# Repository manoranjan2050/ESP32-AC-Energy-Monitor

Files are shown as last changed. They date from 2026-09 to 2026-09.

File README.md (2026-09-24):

# ESP32-S3 AC Energy Monitor (6 CT + voltage), ESPHome / Home Assistant

An open-source, DIY mains energy monitor built on an **ESP32-S3 DevKit**:
- up to **6 SCT-013 current transformers (CTs)**, each channel works with **100A/50mA** or **30A/1V** CTs
- one **ZMPT101B** voltage sensor
- **ESPHome** firmware, visible in **Home Assistant**

> **⚠ Not a certified energy meter.** The ESP32 ADC is noisy and non-linear. Don't use this for
> billing or protection. The board has a **230 V section**, so build and test it only if you're
> competent with mains wiring.

---

## Project status (2026-09-24)

| Part | Status |
|---|---|
| Stage-1 test firmware (1 CT, true RMS, calibration in HA) | ✅ Working (`esphome/energy_monitor_test.yaml`) |
| CT input circuit (bias + 1k/1.8k + 104 + burden) | ✅ **Proven on a breadboard** with both CT types (results below) |
| Custom PCB v0.1 (KiCad): 6 CT + on-board ZMPT101B | ✅ Designed and **fully routed**. ERC 0, DRC 0 errors, schematic ↔ PCB parity 0. **Not built yet** |
| On-board ZMPT101B + MCP6002 voltage stage | ⚠ Designed, **not tested yet** |
| 6-channel + voltage firmware (real power, PF, kWh) | ⏳ Next step (after the PCB) |

### Breadboard test results (CT channel = same values as the PCB)

| CT | Load | Reading | Notes |
|---|---|---|---|
| 30A/1V | CT unclamped | ~0.08 A | Noise floor |
| 30A/1V | Light + fan | **0.33 A** | ≈ 75 W |
| 30A/1V | Water heater | **12.66 A** | Clean sine (pp/rms 2.86), no clipping |
| 100A/50mA + 24 Ω burden | Induction cooker | **4.6 A** | Stable, no clipping |

---

## Repository map

```
esphome/
  energy_monitor_test.yaml      Stage-1 test firmware (1 CT on GPIO1)
  secrets.example.yaml          Copy to secrets.yaml (git-ignored) and fill in Wi-Fi/keys
docs/wiring.md                  Stage-1 breadboard wiring checks
hardware/
  README.md                     PCB design notes, calculations, before-ordering checklist
  kicad/                        KiCad 10 project (schematic + routed PCB + ZMPT101B footprint + DRC rules)
  fab/                          Manufacturing files: Gerbers zip, BOM, pick-and-place, KiCad zip
  renders/                      Diagrams (SVG), PCB images, schematic PDF
  generate_kicad.py             Builds schematic + PCB from ONE netlist (source of truth)
  route_pcb.py                  Hand-routes mains, autoroutes the rest with Freerouting
  make_*_svg.py                 Regenerate the SVG diagrams from the same netlist
```

---

## Files you'll use

### KiCad (schematic + PCB)

| File | What it is |
|---|---|
| [`hardware/kicad/ct6-energy-monitor.kicad_pro`](hardware/kicad/ct6-energy-monitor.kicad_pro) | **Open this in KiCad 10** (free, kicad.org). The schematic and PCB open together |
| [`hardware/kicad/ct6-energy-monitor.kicad_sch`](hardware/kicad/ct6-energy-monitor.kicad_sch) | Schematic: 81 parts, 42 nets |
| [`hardware/kicad/ct6-energy-monitor.kicad_pcb`](hardware/kicad/ct6-energy-monitor.kicad_pcb) | Routed 2-layer PCB, 120 × 90 mm |
| [`hardware/fab/ct6-kicad-project.zip`](hardware/fab/ct6-kicad-project.zip) | The whole KiCad project in one zip |
| [`hardware/renders/schematic.pdf`](hardware/renders/schematic.pdf) | Schematic as a PDF, for viewing and printing |

### EasyEDA

- **EasyEDA Pro:** *File → Import → KiCad*, then pick `ct6-energy-monitor.kicad_pro` or `ct6-kicad-project.zip`.
  The files are **KiCad 10 format**, and EasyEDA's importer may only accept older KiCad versions (**not tested**).
- **EasyEDA Standard:** only imports old KiCad 5 files, so it won't work.
- **If the import fails**, you have three options:
  1. **Order straight from the Gerbers** (below). The board is already routed, so no EasyEDA is needed.
  2. **Redraw in EasyEDA** using [`easyeda_connection_guide.svg`](hardware/renders/easyeda_connection_guide.svg).
     It shows every part, every pin and its net name. Place the parts, put a **Net Label** with the exact
     name on each pin, then check the nets against the list in section 7 of that SVG.
  3. Ask for a **KiCad 6-format copy** of the schematic, which EasyEDA Pro is more likely to accept.

### Ordering (JLCPCB)

| File | Use |
|---|---|
| [`hardware/fab/ct6-gerbers-jlcpcb.zip`](hardware/fab/ct6-gerbers-jlcpcb.zip) | Upload as-is: Gerbers + drill, 2 layers |
| [`hardware/fab/ct6-bom.csv`](hardware/fab/ct6-bom.csv) | Bill of materials |
| [`hardware/fab/ct6-cpl.csv`](hardware/fab/ct6-cpl.csv) | Pick-and-place, origin = bottom-left board corner |

### Diagrams (SVG, open in any browser)

| Diagram | Shows |
|---|---|
| [`pcb_full_connection.svg`](hardware/renders/pcb_full_connection.svg) | **The complete PCB circuit**: every R, C, diode, jumper, op-amp pin and GPIO |
| [`easyeda_connection_guide.svg`](hardware/renders/easyeda_connection_guide.svg) | Every part as a card: pin → net name. Use it for EasyEDA redraws and checks |
| [`final_6ct_voltage_connection.svg`](hardware/renders/final_6ct_voltage_connection.svg) | Breadboard version: 6 CT + ready-made ZMPT101B module |
| [`breadboard_connection.svg`](hardware/renders/breadboard_connection.svg) | Breadboard test of one CT channel (the proven circuit) |
| [`pcb_top.png`](hardware/renders/pcb_top.png), [`pcb_copper.png`](hardware/renders/pcb_copper.png) | PCB 3D render and copper view |

---

## How the circuit works

### GPIO map (ESP32-S3, ADC1 only)

| Signal | GPIO | DevKit socket pin |
|---|---|---|
| CT1 | GPIO1 | J4-4 |
| CT2 · CT3 · CT4 · CT5 | GPIO4 · 5 · 6 · 7 | J3-4 · 5 · 6 · 7 |
| CT6 | GPIO8 | J3-12 |
| Voltage (ZMPT101B) | GPIO9 | J3-15 |
| Bias monitor | GPIO10 | J3-16 |
| I²C OLED SDA / SCL | GPIO17 / GPIO18 | J3-10 / J3-11 |
| 5V in / 3V3 / GND | — | J3-21 / J3-1,2 / J3-22, J4-1,21,22 |

Avoid GPIO0/3/45/46 (strapping), GPIO35–37 (octal PSRAM on N16R8) and GPIO11–20 (ADC2, conflicts with Wi-Fi).
**Measure your DevKit before ordering.** On the test board the silkscreen "4" was really GPIO1.

### One CT channel (×6, identical)

```
CT sleeve ─────────────────────────────────────── VB (bias ≈ 1.5 V)
CT tip ──┬── 1 kΩ ──┬── ADC node ──► GPIO
         │          ├── 1.8 kΩ ──► VB
       22 Ω         ├── 100 nF (104) ──► GND
     (burden,       └── BAT54S clamp (to GND and +3V3A)
   via jumper JP)
```

- **1 kΩ + 1.8 kΩ** scale the signal to **×0.643** around the bias. This gives headroom for 100 A, and the 1 kΩ limits current into the pin.
- **100 nF** filters noise (~2.5 kHz).
- **BAT54S** clamps the pin between 0 and 3.3 V. See "Diodes" below.

### Jumpers JP11…JP16 (one per CT)

| CT type | Shunt position | Burden | Home Assistant settings |
|---|---|---|---|
| **100A/50mA** (SCT-013-000) | **1-2 (mA), default** | IN | Burden **22** (or 24) · Secondary **0.05** · Primary **100** · Calibration **1.555** |
| **30A/1V** (SCT-013-030) | **2-3 (V)** | OUT | Burden **1** · Secondary **1** · Primary **30** · Calibration **1.555** |

- **1.555** undoes the ×0.643 divider. Fine-tune each channel: `Cal = 1.555 × (clamp-meter A ÷ reading A)`.
- **A 1V CT with the shunt on mA** reads ~25 % of the true value. That's safe, just obviously wrong.
- **⚠ A 100A CT with the shunt on V runs OPEN.** The reading clips to 0/4095 and can damage the CT or the pin. **Unclamp immediately.**
- Ship boards with every shunt on **1-2**.

### Diodes (D…)

| Designator | Part | Job |
|---|---|---|
| **D1** | SS34 Schottky | Power input: reverse-polarity protection, and stops USB 5V back-feeding your 5V supply |
| **D11 … D16** | BAT54S | ADC clamps for **CT1 … CT6** (D1**n** = CT**n**, so **D16 = CT6 → GPIO8**) |
| **D41** | BAT54S | ADC clamp for the voltage channel (GPIO9) |

A **BAT54S** is two Schottky diodes in series in one SOT-23:
- **pin 1 = GND side**
- **pin 2 = +3V3A side**
- **pin 3 = ADC node**

It does nothing while the signal is between 0 and 3.3 V. If a fault pushes the pin outside that range (for example a CT without its burden), it clamps the pin. The 1 kΩ in front limits the current. The clamps were optional on the breadboard; **fit them on the PCB.**

### Parts naming (per CT channel n = 1…6)

`J1n` jack · `R1n1` 22 Ω burden · `JP1n` mA/V jumper · `R1n2` 1 kΩ · `R1n3` 1.8 kΩ · `C1n` 100 nF · `D1n` BAT54S

### Resistor colour codes (4-band)

| Value | Bands |
|---|---|
| 10 kΩ | brown · black · orange |
| 1 kΩ | brown · black · red |
| 1.8 kΩ | brown · grey · red |
| 22 Ω | red · red · black |
| 24 Ω | red · yellow · black |
| 18 Ω | brown · grey · black (⚠ not 18 kΩ = brown · grey · orange) |

A ceramic cap marked **104** = 100 nF; **103** = 10 nF; **473** = 47 nF.

---

## Working on another PC

```bash
git clone https://github.com/manoranjan2050/ESP32-AC-Energy-Monitor.git
```

- **PCB:** install KiCad 10 and open `hardware/kicad/ct6-energy-monitor.kicad_pro`.
- **Firmware:** copy `esphome/secrets.example.yaml` to `esphome/secrets.yaml` (git-ignored) and fill in your Wi-Fi and keys.
- **Regenerate** (optional; this overwrites the KiCad files, so **don't** run it after editing the board by hand):

  ```bash
  "C:/Program Files/KiCad/10.0/bin/python.exe" hardware/generate_kicad.py
  ```

## Before ordering the PCB

1. Measure the **DevKit header row spacing** (22.86 mm) and check every pin used.
2. Check the **ZMPT101B pin grid**: 10.0 × 12.7 mm, with calipers.
3. **Screw terminals:** the wire entry faces the board edge.
4. Keep the **6.5 mm mains creepage** and the **slot under T1**.
5. **First power-up without mains and without CTs.** Expect +3V3A ≈ 3.3 V, VB ≈ 1.50 V, and every CTn_ADC / V_ADC ≈ 1.50 V.

Full details are in [`hardware/README.md`](hardware/README.md).

---

## Next steps

1. Order and build PCB v0.1, then test it: the CT channels first, then the on-board voltage stage (untested so far).
2. **6-channel + voltage ESPHome firmware:**
   - per-channel CT type, ratio and calibration
   - V + I sampled together for **real power, power factor, frequency and kWh**
   - Home Assistant **Energy dashboard** support

---

# Stage-1 test firmware guide (1 CT, breadboard)

> The sections below document the **first single-CT test**. Its bias circuit (10k/10k) and direct CT
> wiring were the starting point. The **final, proven channel circuit** adds the 1 kΩ / 1.8 kΩ / 104
> network shown above: use [`breadboard_connection.svg`](hardware/renders/breadboard_connection.svg) and set
> **Calibration 1.555**.

- Board: **ESP32-S3** (QFN56 rev v0.2, 16 MB flash, 8 MB PSRAM, native USB)
- ESPHome: **2026.8.2**, esp-idf framework
- Firmware: [`esphome/energy_monitor_test.yaml`](esphome/energy_monitor_test.yaml)
- Wiring checks: [`docs/wiring.md`](docs/wiring.md)

## 1. Hardware wiring (overview)

```
                     ESP32-S3 3V3
                          │
                         10k
                          │
             ┌────────────┼──────────── BIAS node (~1.65 V)
             │            │                 │
             │           10k            [10 µF, optional
             │            │              but recommended]
             │           GND                │
             │                             GND
   SCT-013-000
   ┌───────────┐
   │ lead A ───┼──────────┬──────── BIAS node
   │           │         22 Ω   (burden, directly across the CT leads)
   │ lead B ───┼──────────┴──────── ESP32-S3 GPIO1 (ADC1_CH0)
   └───────────┘
```

The CT drives an AC voltage across the 22 Ω burden. Because one end of the
burden sits on the 1.65 V bias node, the ADC pin sees **1.65 V ± the AC signal**.

## 2. ESP32 ADC pin configuration

Set the pin in the `substitutions:` block. Give the GPIO **number only**:

```yaml
ct_gpio: "1"     # GPIO1 = ADC1 channel 0 (check the pin electrically; header labels can be misleading)
```

On the ESP32-S3 use an **ADC1 pin, GPIO1 to GPIO10**. Skip GPIO3 (it's a strapping pin).
Don't use ADC2 (GPIO11 to GPIO20), because Wi-Fi uses ADC2.

- Attenuation is **12 dB**. On the S3 that gives about 0 to 3.1 V of usable range.
- Every sample is converted with ESP-IDF's **eFuse curve-fitting calibration**,
  so the ADC is not treated as linear. The diagnostic entity
  **CT ADC Calibration** shows which scheme is active. If it says
  `UNCALIBRATED`, the linear 3.3 V/4095 fallback is in use and the voltages are rough.

## 3. The 22 Ω burden resistor

The SCT-013-000 is a **current-output CT** (100 A : 50 mA) and has **no internal burden**.
The 22 Ω resistor turns its current into a voltage:

| Primary current | Secondary current | Burden RMS | Burden peak | ADC swing (around 1.65 V) |
|---|---|---|---|---|
| 1 A | 0.5 mA  | 11 mV | 15.6 mV | ±0.016 V |
| 4.35 A (1 kW) | 2.17 mA | 47.9 mV | 67.7 mV | ±0.068 V |
| 10 A | 5 mA | 110 mV  | 156 mV  | ±0.156 V |
| 50 A | 25 mA | 550 mV  | 778 mV  | ±0.78 V |
| ~90 A | 45 mA | 990 mV  | 1.40 V  | about the S3 ADC limit |
| 100 A | 50 mA | 1.10 V  | 1.556 V | **clips** (0.09 to 3.21 V) |

With 22 Ω the usable range is about 0 to 90 A. The **CT Clipped Samples** entity counts samples at the ADC rails.

## 4. The 2 × 10 k bias circuit

The two 10 k resistors from 3V3 to GND make a mid-rail point (~1.65 V), so the AC
signal swings around it instead of going below 0 V. Put a
**10 µF to 100 µF capacitor from the bias node to GND**. Without it the bias node
picks up ripple and noise, which shows up as a higher no-load RMS. The firmware
measures the real bias every window (**CT Bias Voltage**), so it doesn't need to be exactly 1.65 V.

## 5. SCT-013-000 connection

The 3.5 mm jack uses **tip** and **sleeve** for the two secondary leads. The ring is
normally unused. Polarity doesn't matter for RMS. Use a 3.5 mm breakout, or cut
the plug and solder the leads. **Fit the burden before clamping the CT on anything.**

## 6. Flashing the ESP32-S3

**Option A: ESPHome Builder (Home Assistant add-on)**
1. ESPHome Builder → **Secrets** (top-right). Add the lines from
   `esphome/secrets.yaml` (not in git; copy `esphome/secrets.example.yaml` and fill in your values) (`wifi_ssid`, `wifi_password`, `ct_test_api_key`,
   `ct_test_ota_password`, `ct_test_ap_password`).
2. **+ New device** → *Continue* → *Skip* the wizard, or create any device and then
   **Edit** it. Replace the whole YAML with `energy_monitor_test.yaml` and save.
3. **Install** → *Plug into this computer* (Chrome/Edge Web Serial), or
   *Manual download* → *Factory format* and flash with web.esphome.io.
4. Later updates can go over the air: **Install → Wirelessly**.

**Option B: ESPHome CLI on this PC**
```bash
cd "D:/My Project/ElectroIoT/ESP32-AC-Energy-Monitor/esphome"
```
```bash
python -m esphome run energy_monitor_test.yaml --device COM5
```
If the S3 won't enter download mode, hold **BOOT**, tap **RST**, then release BOOT.

## 7. Adding it to Home Assistant

The device uses the ESPHome native API, so HA should discover it automatically
(**Settings → Devices & services → Discovered: CT Energy Test → Configure**). When
asked for the encryption key, enter the `ct_test_api_key` value. If it isn't
discovered, add the **ESPHome** integration manually with host `ct-energy-test.local`
(or its IP address) and port `6053`.

Entities (all published together every **5 s**, one window each):

| Entity | Meaning |
|---|---|
| CT Raw ADC | Last raw 12-bit sample in the window |
| CT ADC Voltage | Last sample converted to volts (calibrated) |
| CT Bias Voltage | Mean of the window, which is the DC bias the RMS is taken around |
| CT Minimum / CT Maximum | Lowest and highest raw counts in the window |
| CT Peak-to-Peak | Calibrated V(max) − V(min) |
| CT AC RMS | **True RMS of the AC part across the burden** (bias removed; 400 samples over 10 cycles) |
| CT Secondary / Primary Current (estimated) | Only while **CT Current Estimate Enabled** is on |
| CT Burden Resistance, CT Rated Primary/Secondary Current, CT Calibration Factor | Editable config numbers, kept across reboots |
| CT Clipped Samples, CT Actual Sample Rate, CT ADC Calibration | Diagnostics |

The current estimate is:
```
secondary_A = CT_AC_RMS / burden_resistance
primary_A   = secondary_A × (ct_primary_current / ct_secondary_current) × calibration_factor
```

## 8. Expected values with NO load (CT unclamped or on a dead cable)

| Entity | Expected |
|---|---|
| CT Bias Voltage | ~1.60 to 1.70 V (depends on the 3V3 rail and resistor tolerance) |
| CT Raw ADC / Min / Max | Around the bias count, roughly 1900 to 2300, with Min and Max only a few dozen counts apart |
| CT Peak-to-Peak | Small, about 10 to 60 mV (ADC noise) |
| CT AC RMS | **Low, about 1 to 10 mV** (noise floor) |
| CT Clipped Samples | 0 |
| CT Actual Sample Rate | ~2000 Hz |

Note your no-load RMS. It is the noise floor. As a rough guide, 5 mV of noise
equals about 0.45 A of "phantom" primary current.

## 9. What changes when you clamp a live conductor

Clamp **one** insulated conductor (live **or** neutral), not the whole cable. If
you clamp live and neutral together, their currents cancel and you read about 0.

With a **1000 W resistive load** (~4.35 A at 230 V):

| Entity | Load off | Load on (theory) |
|---|---|---|
| CT Bias Voltage | ~1.65 V | **Unchanged** (~1.65 V) |
| CT Min / Max | ±a few counts | Spread out by roughly ±85 counts |
| CT Peak-to-Peak | ~0.03 V | **~0.14 V** |
| CT AC RMS | ~0.005 V | **~0.048 V** |
| Primary Current (est., if enabled) | ~0.2 to 0.5 A (noise) | **~4.3 A** |

The HA history graph for **CT AC RMS** should step up when the load turns on and
drop when it turns off. To calibrate, compare against a trusted clamp meter and set
`CT Calibration Factor = meter_amps / estimated_amps`. Tip: pass the conductor
through the CT **5 times** (5 turns), so 4.35 A reads like 21.7 A. That gives a much
better signal-to-noise ratio for calibration (divide by 5 afterwards).

## 10. Safety warnings

- **Mains voltage (230 V AC) can kill.** Only clamp an insulated conductor.
  Never open or modify live wiring on a breadboard setup. If you're unsure, have a
  licensed electrician install the CT.
- **Never leave the SCT-013-000 secondary open-circuit while it's clamped on a
  loaded conductor.** A current-output CT with no burden can produce dangerously
  high voltages and damage itself. Keep the 22 Ω burden fitted whenever the CT is
  plugged in or clamped.
- **Never connect the CT directly to the ESP32 without the burden and bias.** The
  ADC pin must stay between 0 V and 3.3 V. A loose bias wire leaves the pin
  swinging below 0 V, which can damage the GPIO.
- The burden must match the current range. 22 Ω clips above ~90 A. For higher
  currents use a smaller burden (for example 18 Ω).
- The ESP32 is powered from USB and is **not isolated from anything except through
  the CT's own insulation**. Keep the breadboard away from the mains side.
- This firmware is not a certified meter. Don't use it for billing, protection, or
  safety decisions.

---

## Original roadmap (written before the 1-channel test)

The 1-channel test has since passed, and the 6-CT PCB is designed. See **Project status** and **Next steps** at the top of this README.

```
ESP32-S3
├── CT1 … CT8   (ADC1 GPIO1..10; per-channel burden + calibration)
└── ZMPT101B    (voltage)
```
Planned: RMS voltage, RMS current per CT, real/apparent power, power factor,
frequency, kWh with the HA Energy dashboard, per-channel calibration, MQTT option, and OTA.
Eight CTs plus a ZMPT101B is 9 analog inputs, which fits in ADC1's 10 pins on the S3. Real power needs
V and I sampled nearly at the same time, so the stage-2 design will use interleaved sampling (or an external
ADC such as the ADS1115/ADS131M08).

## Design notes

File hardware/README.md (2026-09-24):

# CT6 Energy Monitor PCB (v0.1): ESP32-S3 DevKit + 6 CT + ZMPT101B

KiCad 10 project: [`kicad/ct6-energy-monitor.kicad_pro`](kicad/ct6-energy-monitor.kicad_pro)
**Full circuit diagram (every R/C/jumper/GPIO): [`renders/pcb_full_connection.svg`](renders/pcb_full_connection.svg)** · Schematic PDF: [`renders/schematic.pdf`](renders/schematic.pdf) · 3D top view: [`renders/pcb_top.png`](renders/pcb_top.png) · BOM: [`bom.csv`](bom.csv)

> **Status: v0.1 fully routed. Not yet built or tested; do the breadboard test and the checklist below first.**
> ERC: 0 violations · DRC: 0 errors, **0 unconnected**, 0 creepage/clearance · schematic-to-PCB parity: 0 issues.
> Remaining DRC warnings are cosmetic only (silkscreen text overlaps, and the jack's edge marker moved off Edge.Cuts).

**Manufacturing files** (`fab/`):
- `ct6-gerbers-jlcpcb.zip`: Gerbers + drill, upload to JLCPCB as-is
- `ct6-bom.csv` and `ct6-cpl.csv`: BOM and pick-and-place (origin = bottom-left board corner)
- `ct6-kicad-project.zip`: the whole KiCad project

**EasyEDA:** EasyEDA Pro → *File → Import → KiCad*, then select `ct6-kicad-project.zip` (or the `.kicad_pro`).
The files are KiCad 10 format; if your EasyEDA version refuses them, order from the Gerber zip instead.
EasyEDA Standard only imports old KiCad 5 files.

Everything is generated from one netlist in [`generate_kicad.py`](generate_kicad.py), and routed by [`route_pcb.py`](route_pcb.py):
1. The 230 V nets are hand-routed as locked 0.8 mm tracks.
2. **Freerouting 1.9.0** autoroutes the rest, with the whole mains block (+6.5 mm) set as a keepout.
3. The GND pour is added last.

```bash
set CT6_NO_ZONES=1
"C:/Program Files/KiCad/10.0/bin/python.exe" hardware/generate_kicad.py
"C:/Program Files/KiCad/10.0/bin/python.exe" hardware/route_pcb.py path/to/freerouting-1.9.0.jar
```

⚠ Both scripts overwrite the `.kicad_pcb`. **If you edit the board by hand in KiCad, stop rerunning them.**

---

## Block diagram

```
 5V terminal / USB-C ─ polyfuse ─ SS34 ─► DevKit 5V ──► DevKit 3V3 ─ ferrite ─► +3V3A (analog)
                                                                               │
 +3V3A ─ 12k/10k ─► MCP6002-A buffer ─ 47R ─► VB = 1.50 V (10µF+100nF) ────────┼──► GPIO10 (bias monitor)
                                                                               │
 CT1..CT6 jack ─► [22R burden via mA/V jumper] ─ 1k ─┬─ 1k8 → VB              │
                                                      ├─ 100nF → GND           │
                                                      └─ BAT54S clamp ─► GPIO1,4,5,6,7,8
                                                                               │
 230V L/N ─ fuse 100mA ─ MOV ─ 4×220k ─► ZMPT101B ─► MCP6002-B TIA (2k7‖47nF) ─ 1k ─ BAT54S ─► GPIO9
```

## CT input channel (copied from KinCony KC868-M16v2, per channel)

| Part | Value | Purpose |
|---|---|---|
| J1n | 3.5 mm jack (SJ1-3523N) | **Tip = signal, Sleeve = VB**, Ring unused (SCT-013 wiring) |
| R1n1 | **22 Ω 0.1 %** | Burden for **mA-type** CTs (SCT-013-000 100 A/50 mA) |
| JP1n | 3-pin header | **1-2 = mA** (burden in, **ship with this fitted**); **2-3 = V** (burden out, for 1 V CTs such as SCT-013-030) |
| R1n2 / R1n3 | 1 kΩ / 1.8 kΩ 1 % | Attenuator: ×0.643 around VB. The 1 k limits current into the pin; the 1k8 holds an empty jack at VB |
| C1n | 100 nF | Anti-alias / noise filter, ~2.5 kHz |
| D1n | BAT54S | Clamps the ADC pin between GND and 3V3A |

**Headroom at the ADC pin** (1.50 V bias; S3 12 dB range is about 0 to 3.1 V):

| CT | At full scale | At the pin |
|---|---|---|
| SCT-013-000 + 22 Ω (jumper **mA**) | 100 A → 1.10 V RMS | ±1.00 V peak → 0.50 to 2.50 V ✅ |
| SCT-013-030 1 V (jumper **V**) | 30 A → 1.00 V RMS | ±0.91 V peak → 0.59 to 2.41 V ✅ |

Firmware scale (amps per RMS volt **measured at the pin**) = CT ratio ÷ 0.643:
- 100 A/50 mA + 22 Ω: 100 / 0.05 / 22 / 0.643 = **141.4 A/V**
- 30 A/1 V: 30 / 0.643 = **46.7 A/V**

Then fine-tune each channel's calibration factor against a clamp meter.

A **wrong jumper in one direction is safe**: a 1 V CT with the jumper on mA reads only **~25 % of the true value**, because its internal ~67 Ω burden ends up in parallel with the 22 Ω. It's obviously wrong, but harmless. **The dangerous case is an mA CT with the jumper on V.** In that state the CT runs open (the 0/4095 clipping from the breadboard test). That is why mA is the default and the 1k series resistor plus BAT54S protect the pin.

## Voltage channel (ZMPT101B, on board)

- **Primary:** 230 V → F2 100 mA T → 4 × 220 kΩ 1206 (880 kΩ, 57 V per resistor) → 0.26 mA. RV1 (275 VAC MOV) across L/N after the fuse.
- **Secondary:** into MCP6002-B used as a **transimpedance amplifier** with its + input at VB. Output = VB − 0.26 mA × 2.7 kΩ = **1.50 V ± 0.70 V RMS** (±1.0 V peak at 230 V, ±1.2 V at 270 V). 47 nF in parallel sets a ~1.25 kHz roll-off.
- Output goes through 1 kΩ + 100 nF + BAT54S to GPIO9. Calibrate volts in firmware; there's no trimmer.

## GPIO map (ESP32-S3, all ADC1)

| Signal | GPIO | DevKitC-1 pin |
|---|---|---|
| CT1 | GPIO1 | J3-4 (right header) |
| CT2 to CT6 | GPIO4, 5, 6, 7, 8 | J1-4..7, J1-12 (left header) |
| Voltage | GPIO9 | J1-15 |
| Bias monitor | GPIO10 | J1-16 |
| I2C OLED SDA / SCL | GPIO17 / GPIO18 | J1-10 / J1-11 |

Not used: GPIO0/3/45/46 (strapping), GPIO35 to 37 (octal PSRAM on N16R8), GPIO11 to 20 (ADC2, conflicts with Wi-Fi).

## PCB (120 × 90 mm, 2-layer)

- **Mains block** (top-left) is fenced by an **L-shaped 1.6 mm routed slot**. The slot's vertical leg runs **under the ZMPT101B** between primary and secondary pins (10 mm pin-to-pin).
- **Custom DRC rules** (`kicad/ct6-energy-monitor.kicad_dru`): **6.5 mm clearance and creepage** from any `AC_*` net to all low-voltage copper.
- **GND pour** on both layers covers the LV area only. It excludes the mains block and the **DevKit antenna area** (top-right; the DevKit's antenna end sits at the top board edge).
- CT jacks sit on the bottom edge. The DevKit's USB end points down into a clear area, so you can still plug in a USB cable for flashing.

## Before ordering (checklist)

1. **Measure your DevKit.** Header row spacing is set to **22.86 mm** (`DEVKIT_ROW_SPACING`), and the pin order is ESP32-S3-DevKitC-1. Your breadboard test showed the silkscreen didn't match the actual pin (the wire on "4" was GPIO1). **Check every pin used here with a meter or the pin-scan firmware.**
2. **ZMPT101B footprint:** 10.0 × 12.7 mm pin grid, cross-checked against two independent KiCad libraries. Check it against your part with calipers.
3. **Screw terminals J1/J5:** make sure the wire entry faces the board edge (rotate 180° in KiCad if not).
4. **Review the autorouted tracks** in KiCad. Autorouters are functional, not beautiful. The CT signal traces to the DevKit are long diagonals, which is fine at 50 Hz, but you may want to tidy them.
5. After any change, run DRC. It must show **0 unconnected items and 0 creepage errors**.
6. Mains safety: 230 V on a PCB needs an enclosure, a fuse, and no exposed metal. The ZMPT101B is the isolation barrier, so don't bypass it.

## Firmware

Not written yet. Extending `esphome/energy_monitor_test.yaml` to 6 CT + V gives:
- per-channel `ct_gpio`, CT type (mA/V), ratio and calibration
- interleaved V + I sampling for real power, PF and kWh

The on-board **attenuator (×0.643) must be included** in the scale; see the formulas above.

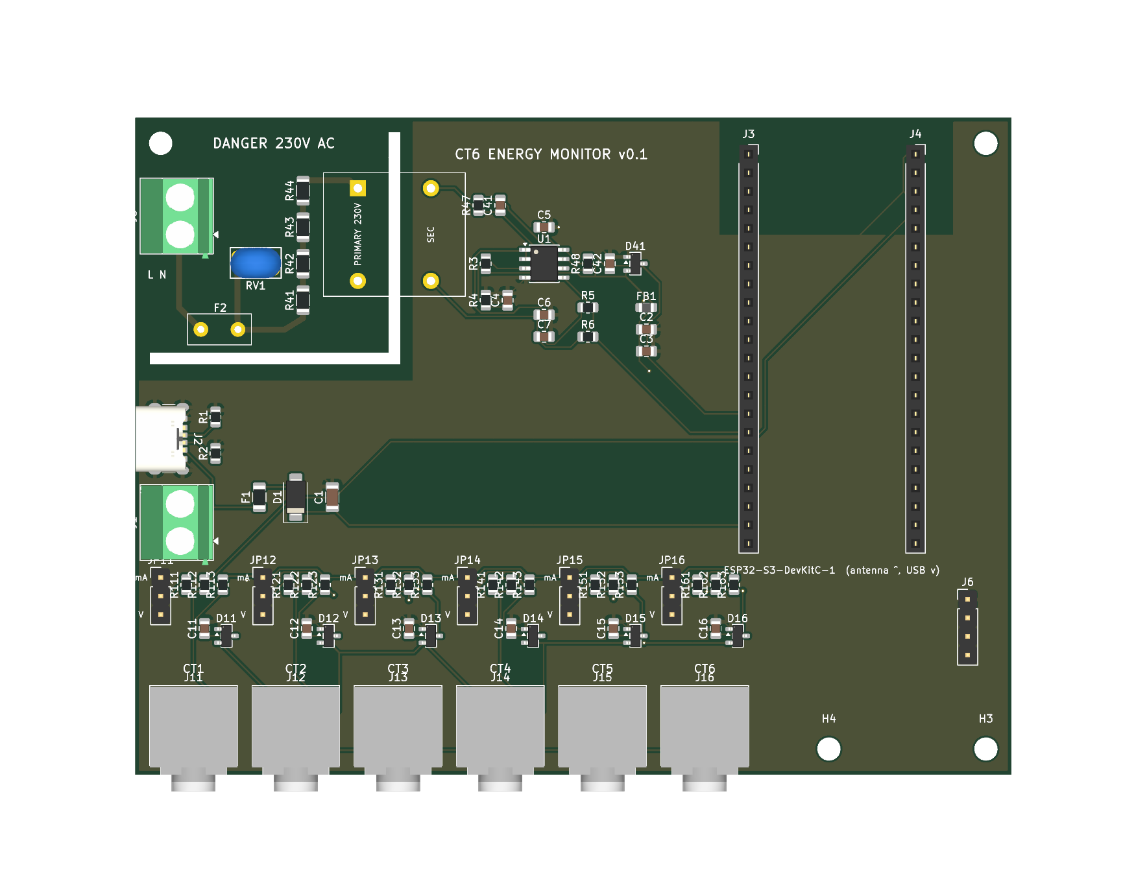
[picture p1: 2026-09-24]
hardware/renders/pcb_top.png

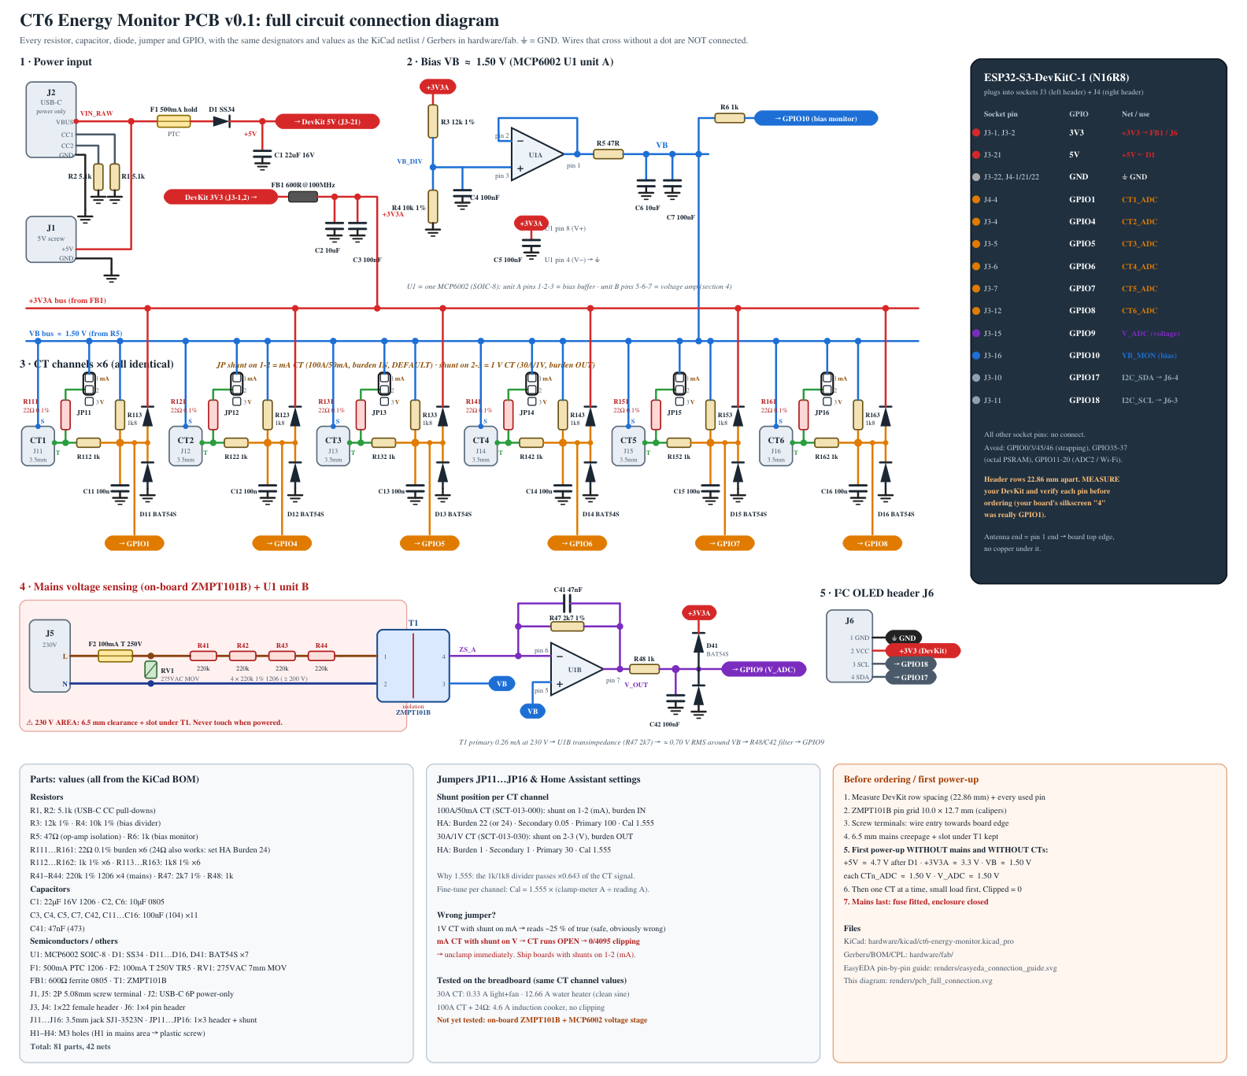
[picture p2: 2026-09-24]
hardware/renders/pcb_full_connection_preview.png

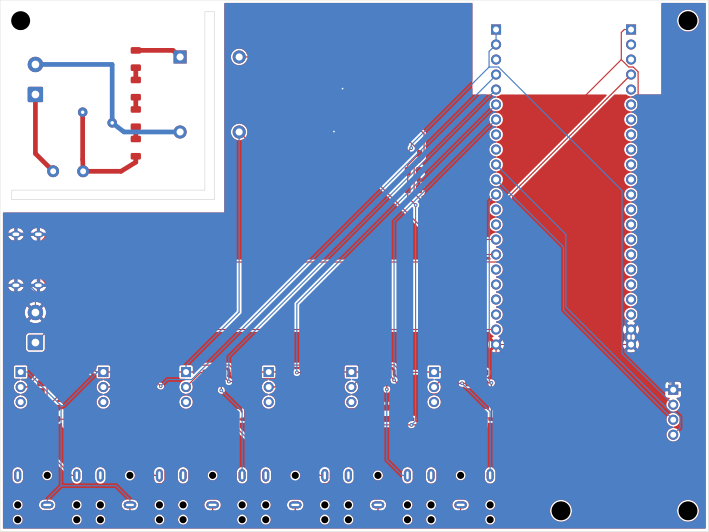
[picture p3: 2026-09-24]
hardware/renders/pcb_copper.png

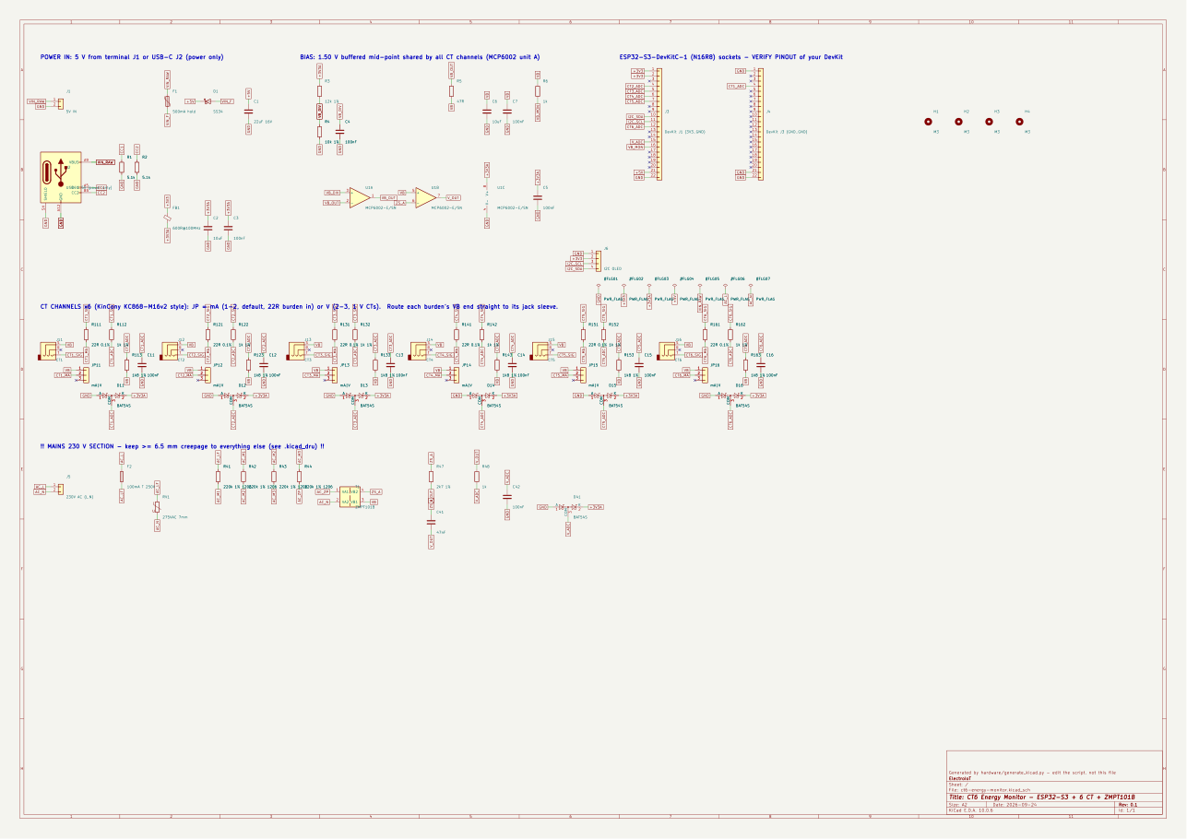
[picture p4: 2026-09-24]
hardware/renders/schematic.png

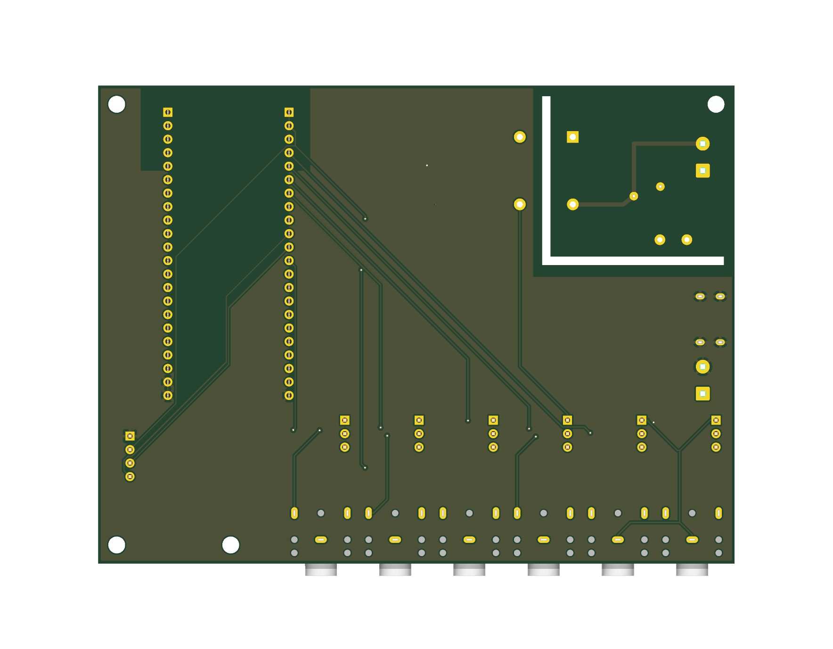
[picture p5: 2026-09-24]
hardware/renders/pcb_bottom.png

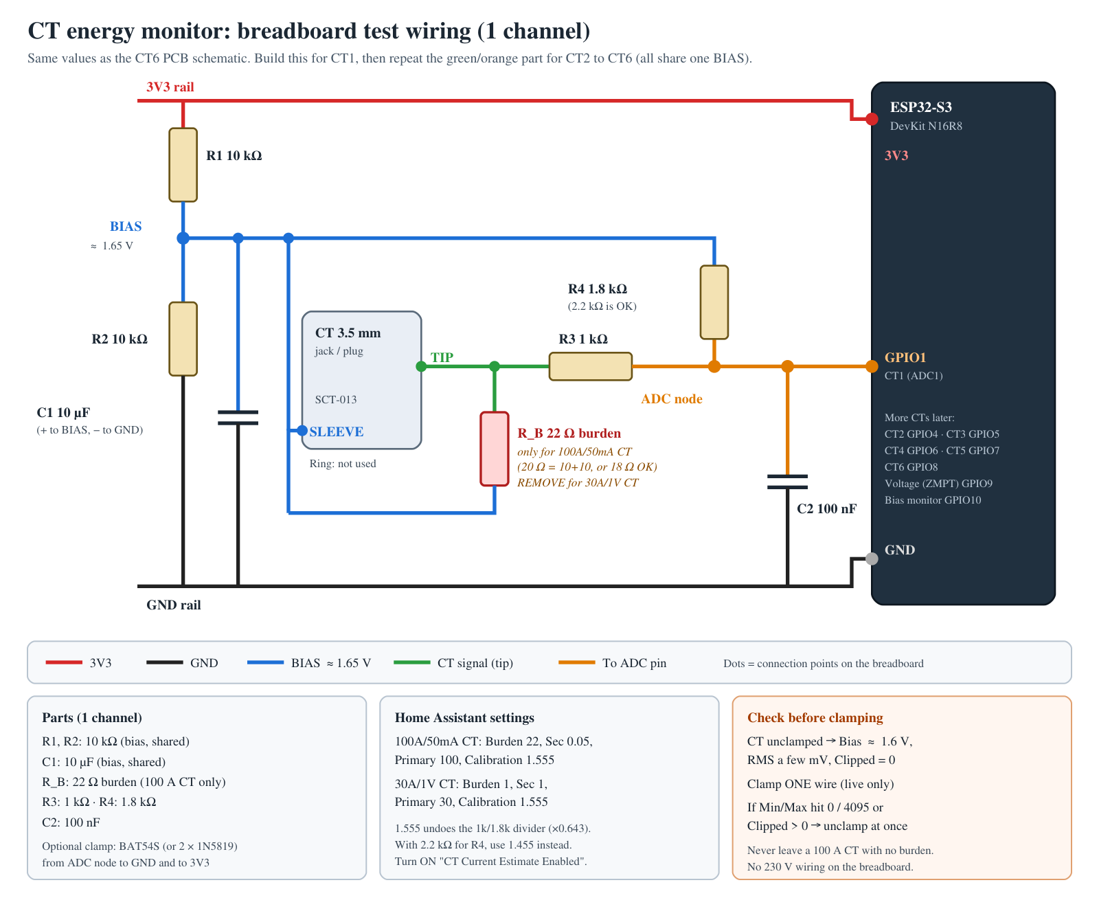
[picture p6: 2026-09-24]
hardware/renders/breadboard_preview.png

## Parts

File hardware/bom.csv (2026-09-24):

Reference | Value | Footprint | QUANTITY
C1 | 22uF 16V | Capacitor_SMD:C_1206_3216Metric | 1
C2,C6 | 10uF | Capacitor_SMD:C_0805_2012Metric | 2
C3-C5,C7,C11-C16,C42 | 100nF | Capacitor_SMD:C_0805_2012Metric | 11
C41 | 47nF | Capacitor_SMD:C_0805_2012Metric | 1
D1 | SS34 | Diode_SMD:D_SMA | 1
D11-D16,D41 | BAT54S | Package_TO_SOT_SMD:SOT-23 | 7
F1 | 500mA hold | Fuse:Fuse_1206_3216Metric | 1
F2 | 100mA T 250V | Fuse:Fuse_Littelfuse_395Series | 1
FB1 | 600R@100MHz | Inductor_SMD:L_0805_2012Metric | 1
J1 | 5V IN | TerminalBlock_Phoenix:TerminalBlock_Phoenix_MKDS-1,5-2-5.08_1x02_P5.08mm_Horizontal | 1
J2 | USB-C 5V (power only) | Connector_USB:USB_C_Receptacle_GCT_USB4125-xx-x_6P_TopMnt_Horizontal | 1
J3 | DevKit J1 (3V3..GND) | Connector_PinSocket_2.54mm:PinSocket_1x22_P2.54mm_Vertical | 1
J4 | DevKit J3 (GND..GND) | Connector_PinSocket_2.54mm:PinSocket_1x22_P2.54mm_Vertical | 1
J5 | 230V AC (L,N) | TerminalBlock_Phoenix:TerminalBlock_Phoenix_MKDS-1,5-2-5.08_1x02_P5.08mm_Horizontal | 1
J6 | I2C OLED | Connector_PinHeader_2.54mm:PinHeader_1x04_P2.54mm_Vertical | 1
J11 | CT1 | Connector_Audio:Jack_3.5mm_CUI_SJ1-3523N_Horizontal | 1
J12 | CT2 | Connector_Audio:Jack_3.5mm_CUI_SJ1-3523N_Horizontal | 1
J13 | CT3 | Connector_Audio:Jack_3.5mm_CUI_SJ1-3523N_Horizontal | 1
J14 | CT4 | Connector_Audio:Jack_3.5mm_CUI_SJ1-3523N_Horizontal | 1
J15 | CT5 | Connector_Audio:Jack_3.5mm_CUI_SJ1-3523N_Horizontal | 1
J16 | CT6 | Connector_Audio:Jack_3.5mm_CUI_SJ1-3523N_Horizontal | 1
JP11-JP16 | mA|V | Connector_PinHeader_2.54mm:PinHeader_1x03_P2.54mm_Vertical | 6
R1,R2 | 5.1k | Resistor_SMD:R_0805_2012Metric | 2
R3 | 12k 1% | Resistor_SMD:R_0805_2012Metric | 1
R4 | 10k 1% | Resistor_SMD:R_0805_2012Metric | 1
R5 | 47R | Resistor_SMD:R_0805_2012Metric | 1
R6,R48 | 1k | Resistor_SMD:R_0805_2012Metric | 2
R41-R44 | 220k 1% 1206 | Resistor_SMD:R_1206_3216Metric | 4
R47 | 2k7 1% | Resistor_SMD:R_0805_2012Metric | 1
R111,R121,R131,R141,R151,R161 | 22R 0.1% | Resistor_SMD:R_0805_2012Metric | 6
R112,R122,R132,R142,R152,R162 | 1k 1% | Resistor_SMD:R_0805_2012Metric | 6
R113,R123,R133,R143,R153,R163 | 1k8 1% | Resistor_SMD:R_0805_2012Metric | 6
RV1 | 275VAC 7mm | Varistor:RV_Disc_D7mm_W4.2mm_P5mm | 1
T1 | ZMPT101B | ct6:ZMPT101B | 1
U1 | MCP6002-E/SN | Package_SO:SOIC-8_3.9x4.9mm_P1.27mm | 1

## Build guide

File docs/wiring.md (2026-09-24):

# Breadboard wiring: single SCT-013-000 channel on the ESP32-S3

| From | To | Notes |
|---|---|---|
| ESP32-S3 **3V3** | R1 (10 k), top end | |
| R1 bottom end | **BIAS** row | |
| **BIAS** row | R2 (10 k), top end | |
| R2 bottom end | ESP32-S3 **GND** | |
| **BIAS** row | 10 µF capacitor (+) | Optional but recommended; (−) to GND |
| **BIAS** row | CT lead A (jack **sleeve**) | |
| CT lead B (jack **tip**) | **ADC** row | |
| 22 Ω burden | between **BIAS** row and **ADC** row | directly across the CT leads |
| **ADC** row | ESP32-S3 **GPIO1** | or any ADC1 pin GPIO1..10 (not GPIO3); set `ct_gpio` to match |

Checks before you clamp anything (USB power only):

1. Multimeter DC V from BIAS to GND should read about 1.65 V.
2. Measure the resistance across the CT jack with the CT plugged in. It should read about 15 to 22 Ω
   (the 22 Ω burden in parallel with the CT winding's DC resistance). If it reads open-circuit, the burden isn't connected. **Do not clamp.**
3. In HA, **CT Bias Voltage** should match your meter to within about 20 mV, and **CT AC RMS** should be low.

Only after those checks, clamp the CT around **one** insulated conductor.

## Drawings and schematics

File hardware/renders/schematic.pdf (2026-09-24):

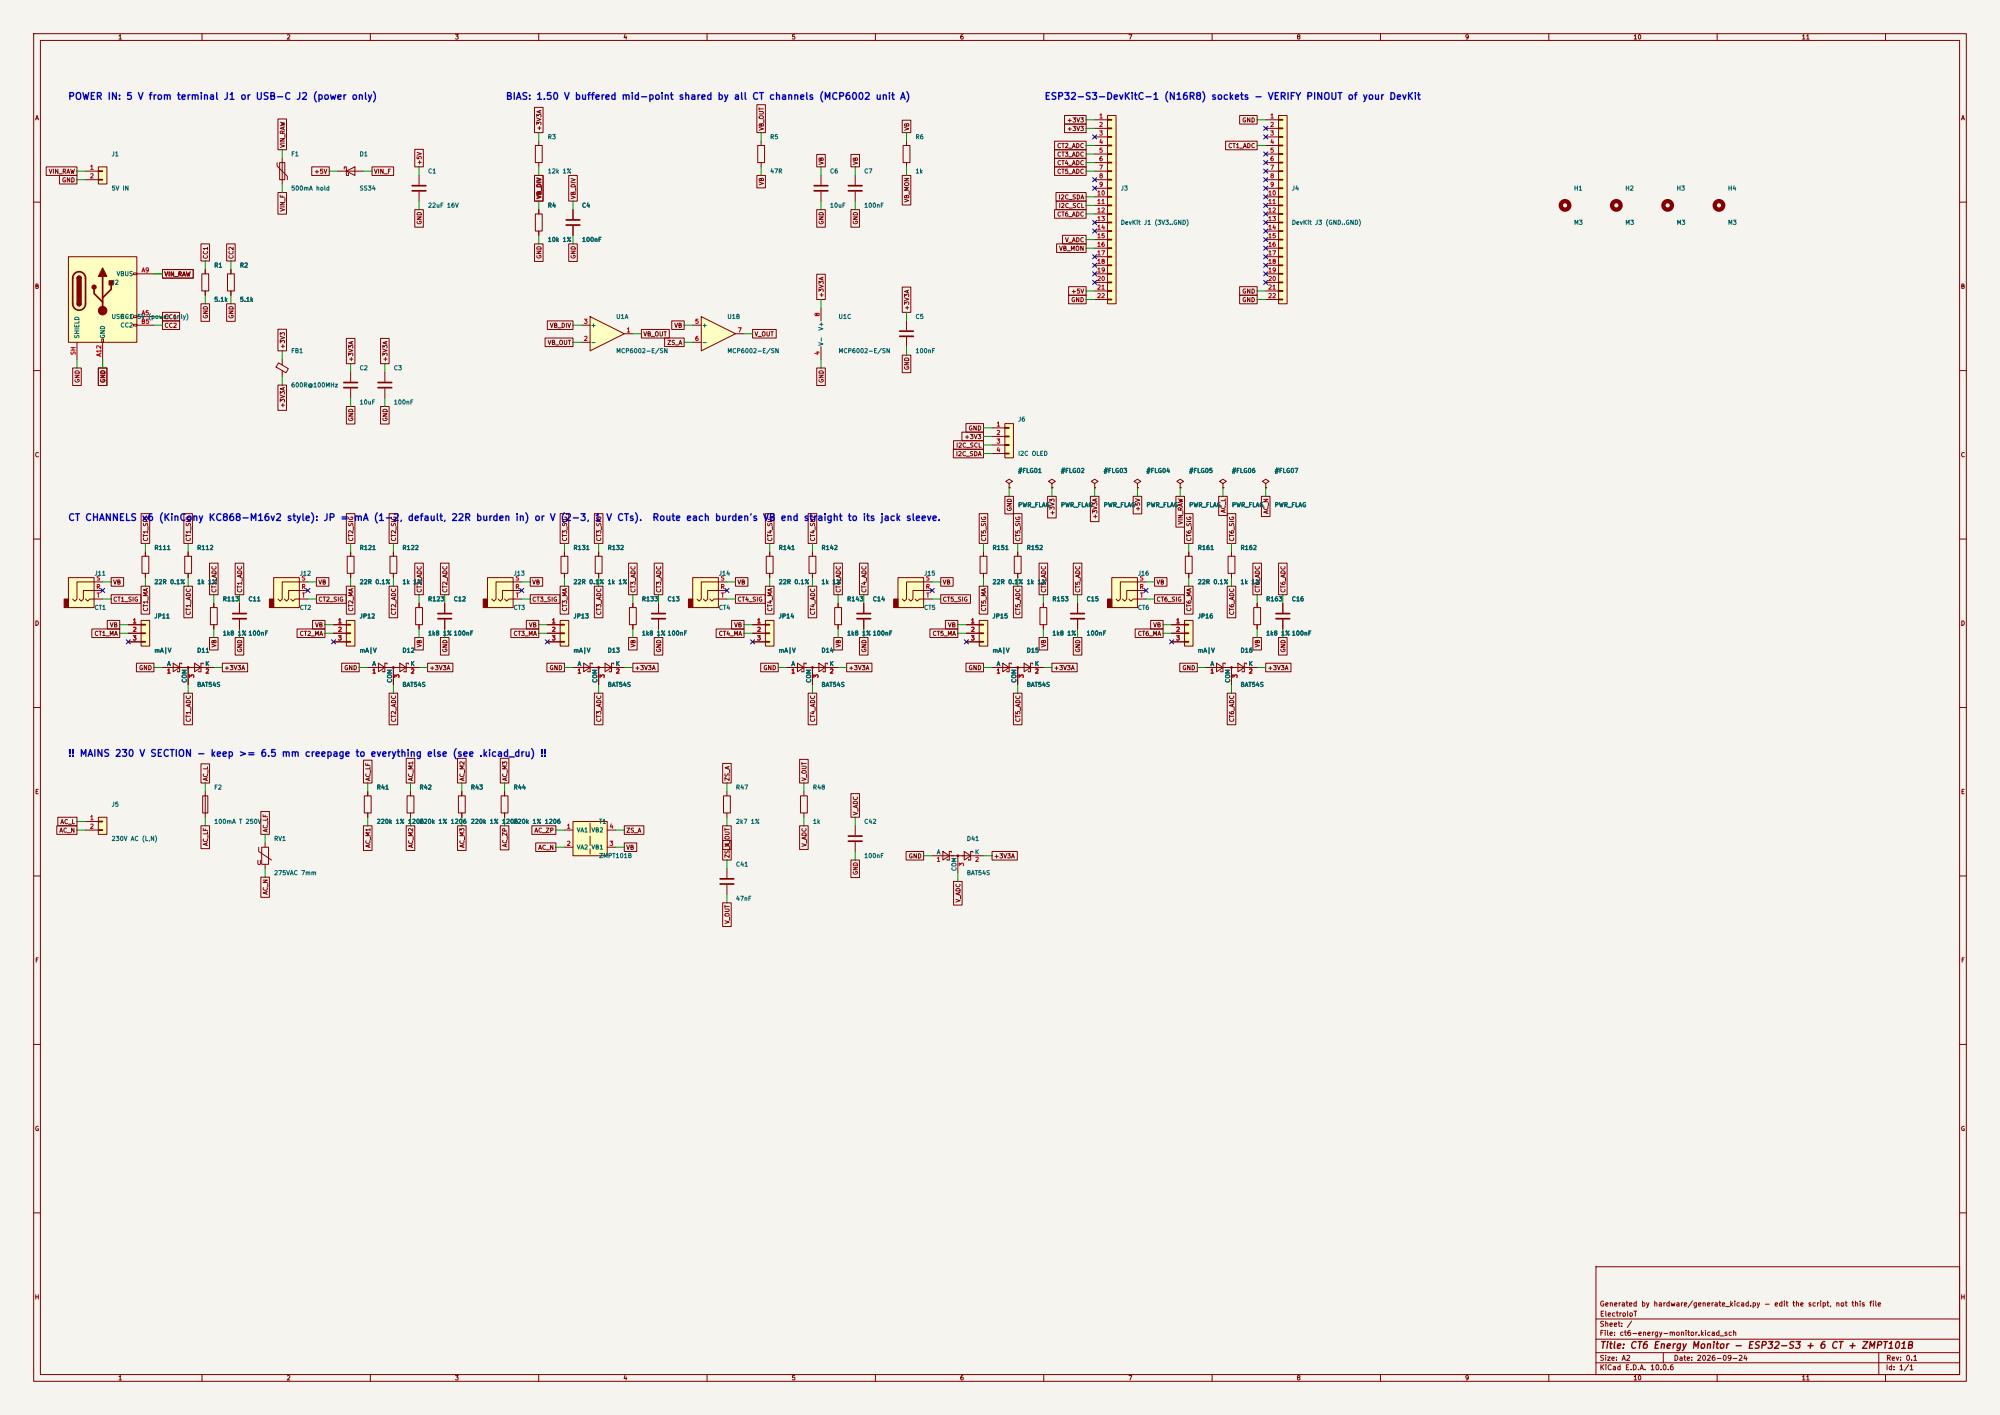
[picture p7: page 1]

ESP32-S3-DevKitC-1 (N16R8) sockets - VERIFY PINOUT of your DevKit

!! MAINS 230 V SECTION - keep >= 6.5 mm creepage to everything else (see .kicad_dru) !!

Generated by hardware/generate_kicad.py - edit the script, not this file
ElectroIoT
Sheet: /
File: ct6-energy-monitor.kicad_sch
Title: CT6 Energy Monitor - ESP32-S3 + 6 CT + ZMPT101B

Size: A2 | Rev: 0.1
KiCad E.D.A. 10.0.6 | Id: 1/1

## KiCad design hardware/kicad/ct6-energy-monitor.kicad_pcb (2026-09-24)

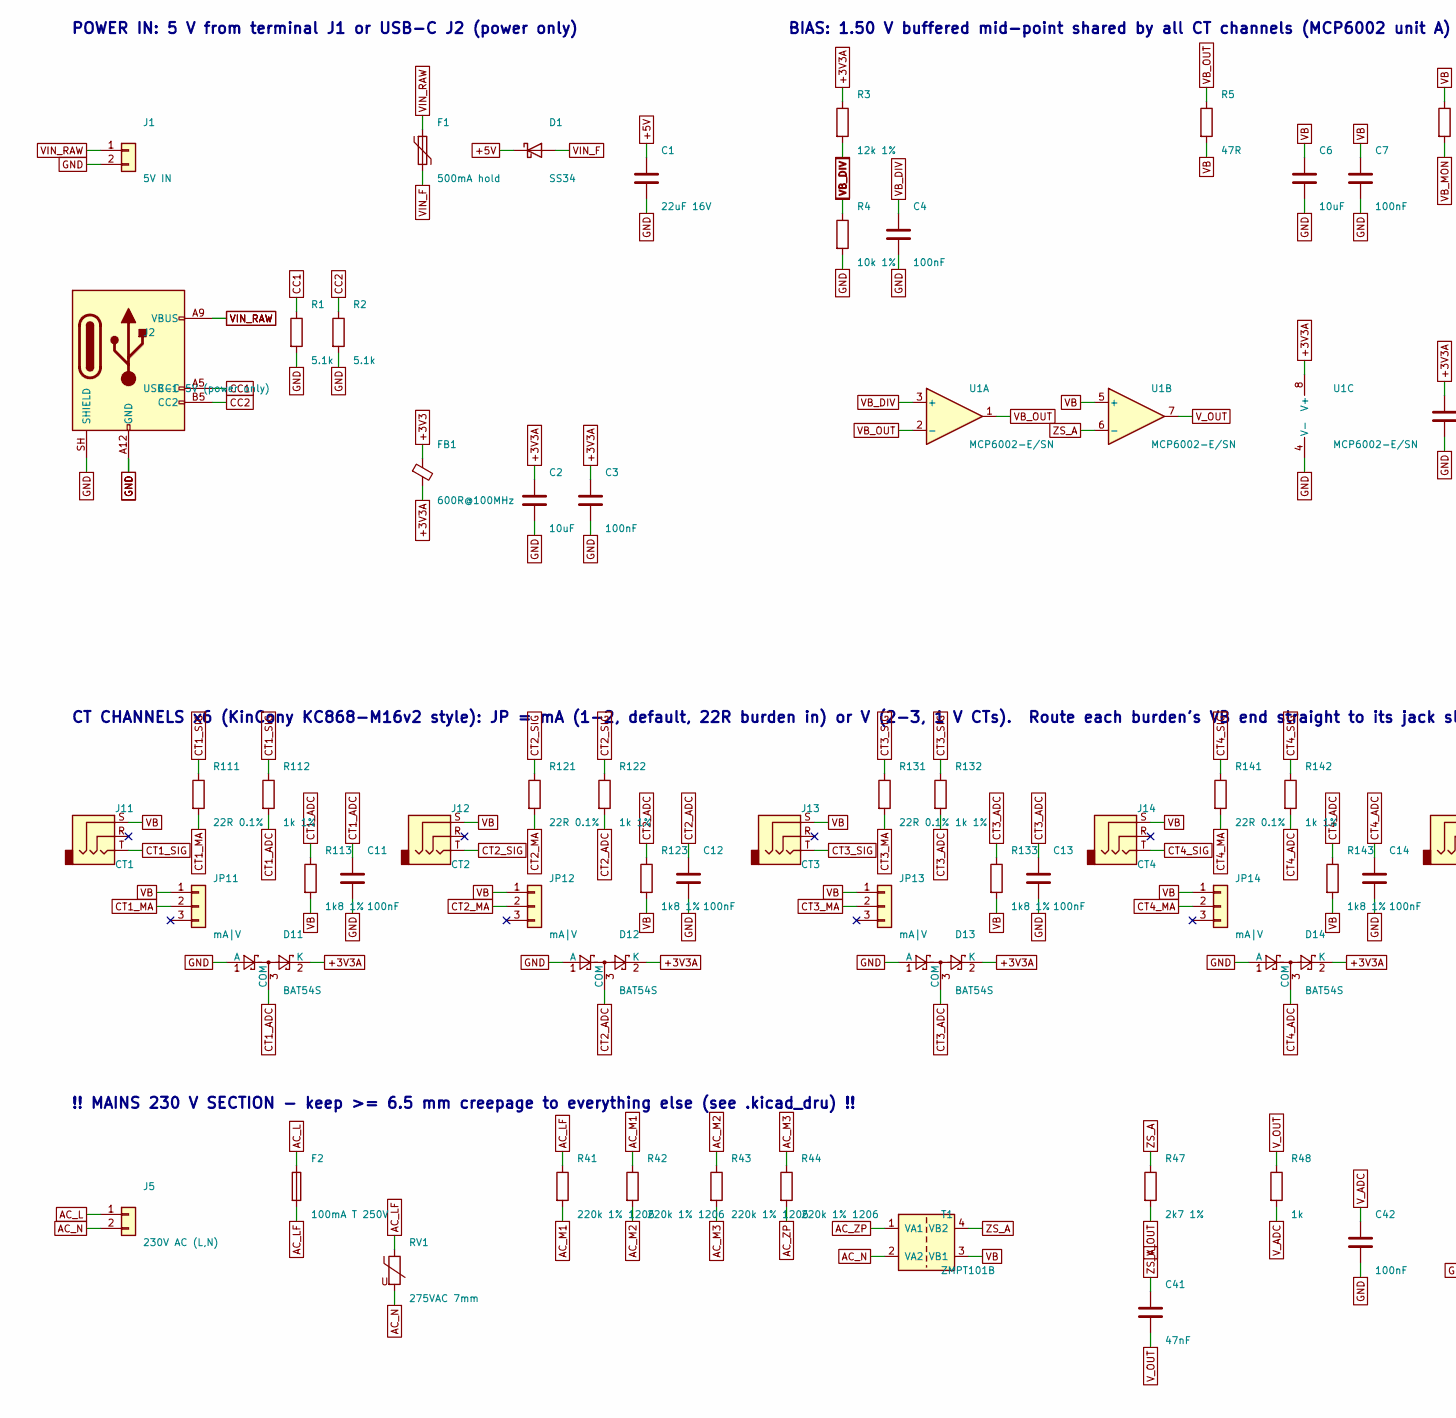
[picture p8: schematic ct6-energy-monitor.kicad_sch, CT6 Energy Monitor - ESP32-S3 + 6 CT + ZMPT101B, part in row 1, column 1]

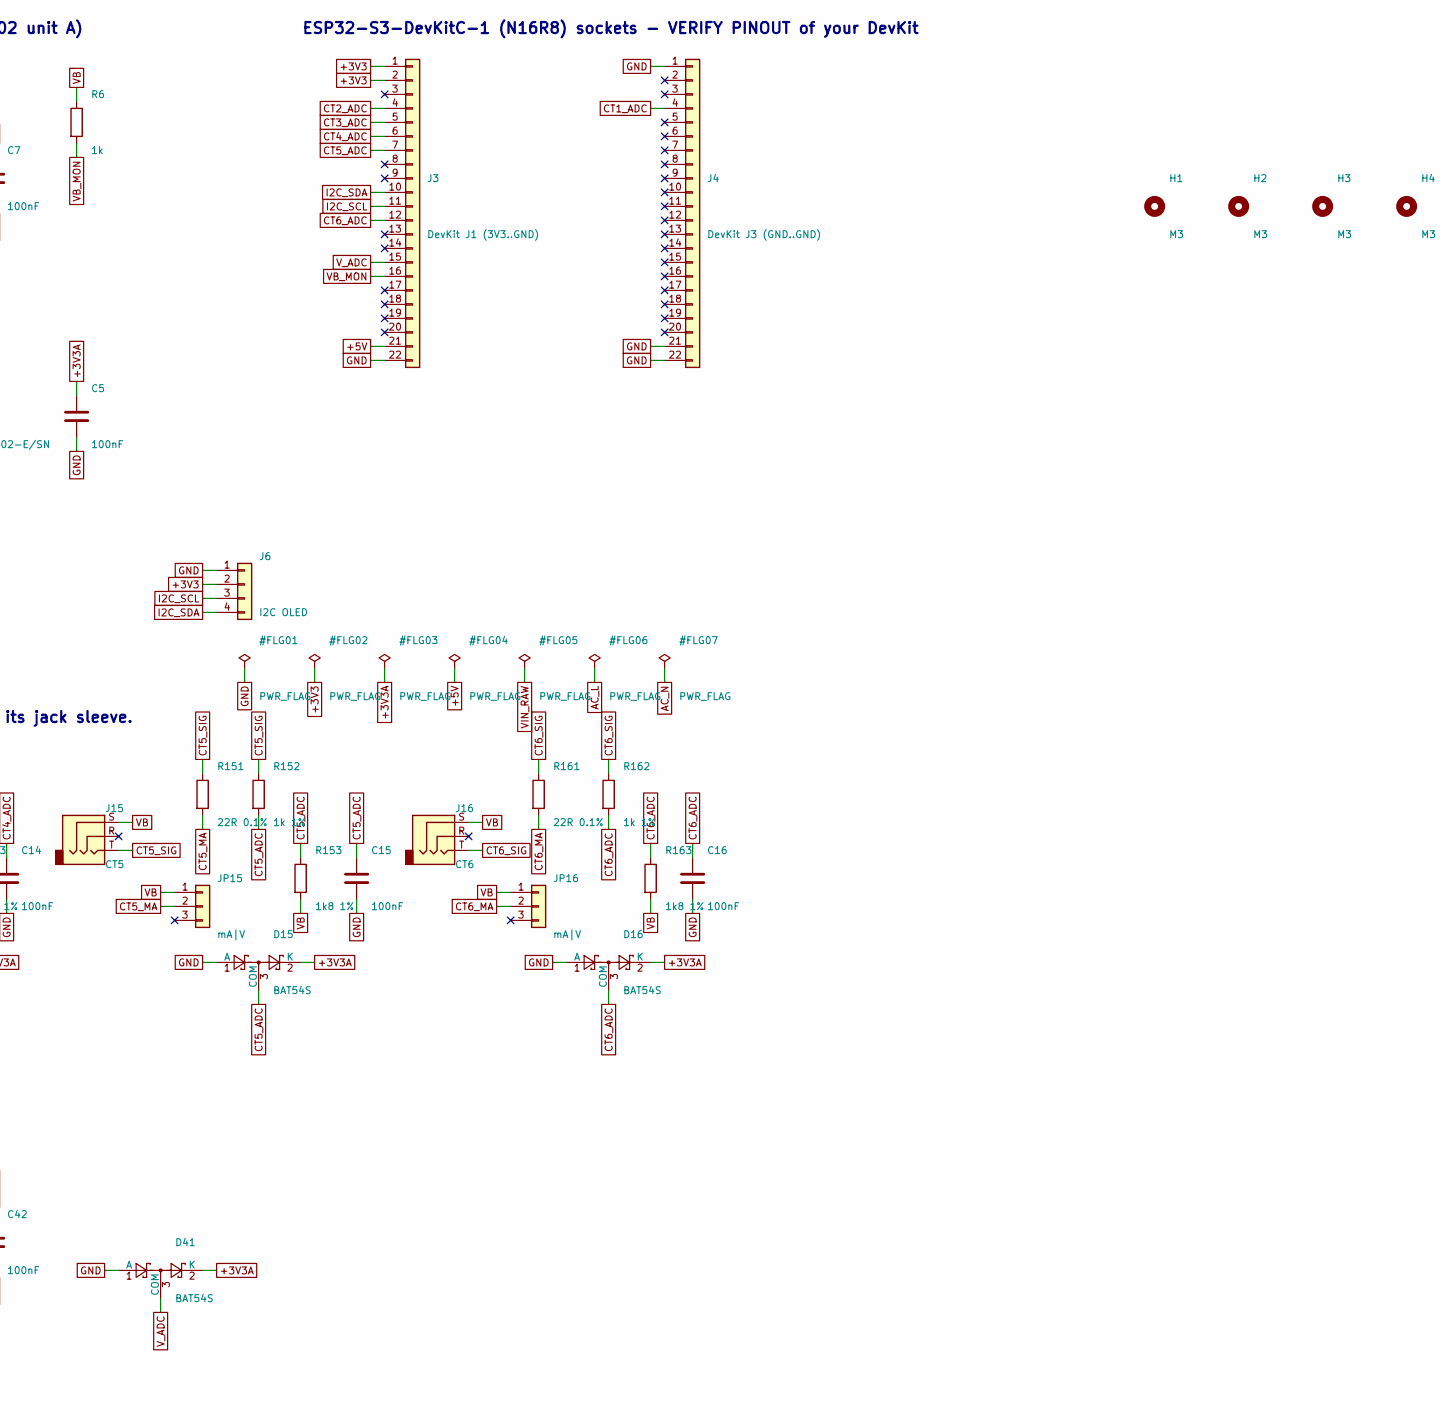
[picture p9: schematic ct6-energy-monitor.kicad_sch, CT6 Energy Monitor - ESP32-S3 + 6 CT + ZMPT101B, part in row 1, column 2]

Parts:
C1: 22uF 16V; C_1206_3216Metric
C2, C6: 10uF; C_0805_2012Metric
C3, C4, C5, C7, C11, C12, C13, C14, C15, C16, C42: 100nF; C_0805_2012Metric
C41: 47nF; C_0805_2012Metric
D1: SS34; D_SMA
D11, D12, D13, D14, D15, D16, D41: BAT54S; SOT-23
F1: 500mA hold; Fuse_1206_3216Metric
F2: 100mA T 250V; Fuse_Littelfuse_395Series
FB1: 600R@100MHz; L_0805_2012Metric
H1, H2, H3, H4: M3; MountingHole_3.2mm_M3
J1: 5V IN; TerminalBlock_Phoenix_MKDS-1,5-2-5.08_1x02_P5.08mm_Horizont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
J2: USB-C 5V (power only); USB_C_Receptacle_GCT_USB4125-xx-x_6P_TopMnt_Horizontal
J3: DevKit J1 (3V3..GND); PinSocket_1x22_P2.54mm_Vertical
J4: DevKit J3 (GND..GND); PinSocket_1x22_P2.54mm_Vertical
J5: 230V AC (L,N); TerminalBlock_Phoenix_MKDS-1,5-2-5.08_1x02_P5.08mm_Horizont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
J6: I2C OLED; PinHeader_1x04_P2.54mm_Vertical
J11: CT1; Jack_3.5mm_CUI_SJ1-3523N_Horizontal
J12: CT2; Jack_3.5mm_CUI_SJ1-3523N_Horizontal
J13: CT3; Jack_3.5mm_CUI_SJ1-3523N_Horizontal
J14: CT4; Jack_3.5mm_CUI_SJ1-3523N_Horizontal
J15: CT5; Jack_3.5mm_CUI_SJ1-3523N_Horizontal
J16: CT6; Jack_3.5mm_CUI_SJ1-3523N_Horizontal
JP11, JP12, JP13, JP14, JP15, JP16: mA|V; PinHeader_1x03_P2.54mm_Vertical
R1, R2: 5.1k; R_0805_2012Metric
R3: 12k 1%; R_0805_2012Metric
R4: 10k 1%; R_0805_2012Metric
R5: 47R; R_0805_2012Metric
R6, R48: 1k; R_0805_2012Metric
R41, R42, R43, R44: 220k 1% 1206; R_1206_3216Metric
R47: 2k7 1%; R_0805_2012Metric
R111, R121, R131, R141, R151, R161: 22R 0.1%; R_0805_2012Metric
R112, R122, R132, R142, R152, R162: 1k 1%; R_0805_2012Metric
R113, R123, R133, R143, R153, R163: 1k8 1%; R_0805_2012Metric
RV1: 275VAC 7mm; RV_Disc_D7mm_W4.2mm_P5mm
T1: ZMPT101B
U1: MCP6002-E/SN; SOIC-8_3.9x4.9mm_P1.27mm

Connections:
+3V3: FB1.1, J3.1, J3.2, J6.2
+3V3A: C2.1, C3.1, C5.1, D11.2 (K), D12.2 (K), D13.2 (K), D14.2 (K), D15.2 (K), D16.2 (K), D41.2 (K), FB1.2, R3.1, U1.8 (V+)
+5V: C1.1, D1.1 (K), J3.21
AC_L: F2.1, J5.1
AC_LF: F2.2, R41.1, RV1.1
AC_M1: R41.2, R42.1
AC_M2: R42.2, R43.1
AC_M3: R43.2, R44.1
AC_N: J5.2, RV1.2, T1.2 (VA2)
AC_ZP: R44.2, T1.1 (VA1)
CC1: J2.A5 (CC1), R1.1
CC2: J2.B5 (CC2), R2.1
CT1_ADC: C11.1, D11.3 (COM), J4.4, R112.2, R113.1
CT1_MA: JP11.2, R111.2
CT1_SIG: J11.T, R111.1, R112.1
CT2_ADC: C12.1, D12.3 (COM), J3.4, R122.2, R123.1
CT2_MA: JP12.2, R121.2
CT2_SIG: J12.T, R121.1, R122.1
CT3_ADC: C13.1, D13.3 (COM), J3.5, R132.2, R133.1
CT3_MA: JP13.2, R131.2
CT3_SIG: J13.T, R131.1, R132.1
CT4_ADC: C14.1, D14.3 (COM), J3.6, R142.2, R143.1
CT4_MA: JP14.2, R141.2
CT4_SIG: J14.T, R141.1, R142.1
CT5_ADC: C15.1, D15.3 (COM), J3.7, R152.2, R153.1
CT5_MA: JP15.2, R151.2
CT5_SIG: J15.T, R151.1, R152.1
CT6_ADC: C16.1, D16.3 (COM), J3.12, R162.2, R163.1
CT6_MA: JP16.2, R161.2
CT6_SIG: J16.T, R161.1, R162.1
GND: C1.2, C2.2, C3.2, C4.2, C5.2, C6.2, C7.2, C11.2, C12.2, C13.2, C14.2, C15.2, C16.2, C42.2, D11.1 (A), D12.1 (A), D13.1 (A), D14.1 (A), D15.1 (A), D16.1 (A), D41.1 (A), J1.2, J2.A12 (GND), J2.B12 (GND), J2.SH (SHIELD), J3.22, J4.1, J4.21, J4.22, J6.1, R1.2, R2.2, R4.2, U1.4 (V-)
I2C_SCL: J3.11, J6.3
I2C_SDA: J3.10, J6.4
VB: C6.1, C7.1, J11.S, J12.S, J13.S, J14.S, J15.S, J16.S, JP11.1, JP12.1, JP13.1, JP14.1, JP15.1, JP16.1, R5.2, R6.1, R113.2, R123.2, R133.2, R143.2, R153.2, R163.2, T1.3 (VB1), U1.5 (+)
VB_DIV: C4.1, R3.2, R4.1, U1.3 (+)
VB_MON: J3.16, R6.2
VB_OUT: R5.1, U1.1, U1.2 (-)
VIN_F: D1.2 (A), F1.2
VIN_RAW: F1.1, J1.1, J2.A9 (VBUS), J2.B9 (VBUS)
V_ADC: C42.1, D41.3 (COM), J3.15, R48.2
V_OUT: C41.2, R47.2, R48.1, U1.7
ZS_A: C41.1, R47.1, T1.4 (VB2), U1.6 (-)

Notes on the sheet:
POWER IN: 5 V from terminal J1 or USB-C J2 (power only)
BIAS: 1.50 V buffered mid-point shared by all CT channels (MCP6002 unit A)
CT CHANNELS x6 (KinCony KC868-M16v2 style): JP = mA (1-2, default, 22R burden in) or V (2-3, 1 V CTs). Route each burden's VB end straight to its jack sleeve.
!! MAINS 230 V SECTION - keep >= 6.5 mm creepage to everything else (see .kicad_dru) !!
ESP32-S3-DevKitC-1 (N16R8) sockets - VERIFY PINOUT of your DevKit

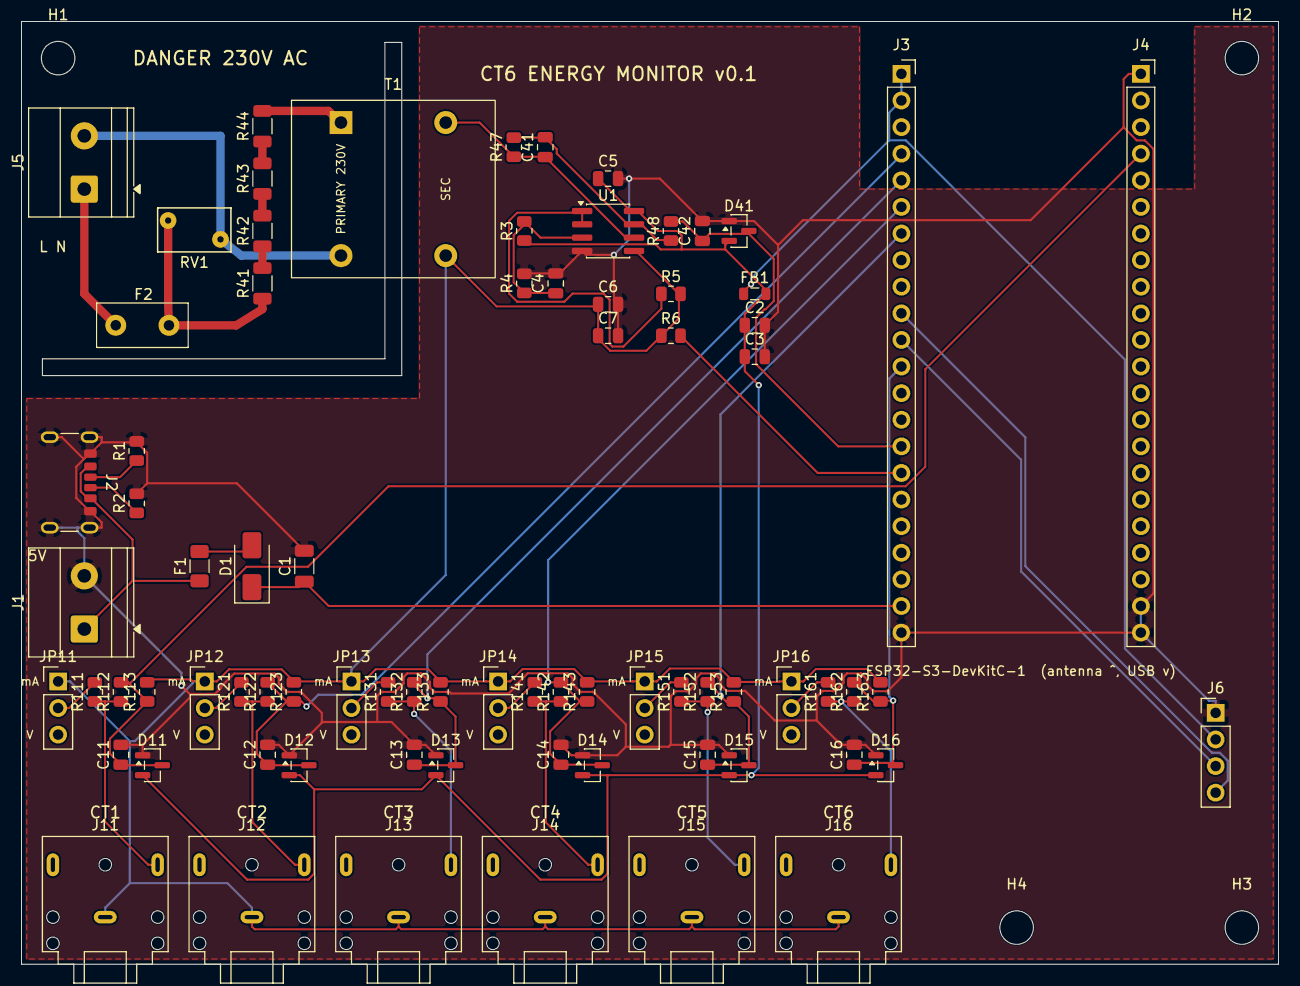
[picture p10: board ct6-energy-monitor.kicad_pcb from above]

Board: 2 copper layers, 120.0 x 90.0 mm, 81 parts (0 on the bottom side), 42 nets.

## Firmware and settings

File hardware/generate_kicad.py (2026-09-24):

"""
Generate the CT6 energy-monitor KiCad project (schematic + placed PCB) from ONE netlist.

Run with KiCad's bundled Python (it provides the `pcbnew` module):
    "C:/Program Files/KiCad/10.0/bin/python.exe" hardware/generate_kicad.py

Outputs into hardware/kicad/:
    ct6-energy-monitor.kicad_pro / .kicad_sch / .kicad_pcb / .kicad_dru
    ct6.pretty/ZMPT101B.kicad_mod, ct6.kicad_sym, fp-lib-table, sym-lib-table

The schematic connects every pin with a short wire + net label (no long wires), so the
netlist below is the single source of truth. The PCB is PLACED but NOT ROUTED.
"""
import copy
import json
import math
import os
import re
import uuid

KICAD = "C:/Program Files/KiCad/10.0/share/kicad"
HERE = os.path.dirname(os.path.abspath(__file__))
OUT = os.path.join(HERE, "kicad")
NAME = "ct6-energy-monitor"
PROJECT_UUID_NS = uuid.UUID("6b1f3c1e-6a53-4a8e-9f0c-2c6d0e2f7a10")

# DevKit header spacing (centre-to-centre of the two 1x22 sockets).
# ESP32-S3-DevKitC-1 = 22.86 mm (0.9"). MEASURE YOUR BOARD before ordering.
DEVKIT_ROW_SPACING = 22.86


def uid(*parts):
    """Deterministic UUIDs so regenerating keeps KiCad links stable."""
    return str(uuid.uuid5(PROJECT_UUID_NS, "/".join(str(p) for p in parts)))


# ============================================================================
# S-expression helpers
# ============================================================================
class Q(str):
    """A quoted string atom."""


def parse(text):
    tokens = re.findall(r'\(|\)|"(?:\\.|[^"\\])*"|[^\s()"]+', text)
    stack = [[]]
    for t in tokens:
        if t == "(":
            stack.append([])
        elif t == ")":
            node = stack.pop()
            stack[-1].append(node)
        elif t.startswith('"'):
            stack[-1].append(Q(t[1:-1].replace('\\"', '"').replace("\\\\", "\\")))
        else:
            stack[-1].append(t)
    return stack[0][0]


def dump(node, indent=0):
    if isinstance(node, list):
        if not any(isinstance(c, list) for c in node):
            return "(" + " ".join(dump(c) for c in node) + ")"
        pad = "\t" * (indent + 1)
        inner = []
        for c in node:
            inner.append(dump(c, indent + 1) if isinstance(c, list) else dump(c))
        head = []
        rest = []
        for c, s in zip(node, inner):
            (rest if (isinstance(c, list) or rest) else head).append(s)
        return "(" + " ".join(head) + "".join("\n" + pad + s for s in rest) + "\n" + "\t" * indent + ")"
    if isinstance(node, Q):
        return '"' + node.replace("\\", "\\\\").replace('"', '\\"') + '"'
    if isinstance(node, float):
        s = f"{node:.4f}".rstrip("0").rstrip(".")
        return s if s not in ("-0", "") else "0"
    return str(node)


def find(node, head):
    return [c for c in node if isinstance(c, list) and c and c[0] == head]


def first(node, head):
    r = find(node, head)
    return r[0] if r else None


# ============================================================================
# Symbol library access (with `extends` flattening)
# ============================================================================
_lib_cache = {}


def lib_symbols(lib):
    if lib not in _lib_cache:
        path = os.path.join(KICAD, "symbols", lib + ".kicad_sym")
        _lib_cache[lib] = {s[1]: s for s in find(parse(open(path, encoding="utf-8").read()), "symbol")}
    return _lib_cache[lib]


CUSTOM_SYMBOLS_TEXT = r'''
(kicad_symbol_lib (version 20241209) (generator "ct6_gen")
 (symbol "ZMPT101B" (pin_names (offset 1.016)) (exclude_from_sim no) (in_bom yes) (on_board yes)
  (property "Reference" "T" (at 0 7.62 0) (effects (font (size 1.27 1.27))))
  (property "Value" "ZMPT101B" (at 0 -7.62 0) (effects (font (size 1.27 1.27))))
  (property "Footprint" "ct6:ZMPT101B" (at 0 0 0) (hide yes) (effects (font (size 1.27 1.27))))
  (property "Datasheet" "" (at 0 0 0) (hide yes) (effects (font (size 1.27 1.27))))
  (property "Description" "ZMPT101B 2mA:2mA precision voltage transformer (1000:1000)" (at 0 0 0) (hide yes) (effects (font (size 1.27 1.27))))
  (symbol "ZMPT101B_0_1"
   (rectangle (start -5.08 5.08) (end 5.08 -5.08) (stroke (width 0.254) (type default)) (fill (type background)))
   (polyline (pts (xy 0 4.572) (xy 0 -4.572)) (stroke (width 0.254) (type dash)) (fill (type none))))
  (symbol "ZMPT101B_1_1"
   (pin passive line (at -7.62 2.54 0) (length 2.54) (name "VA1" (effects (font (size 1.27 1.27)))) (number "1" (effects (font (size 1.27 1.27)))))
   (pin passive line (at -7.62 -2.54 0) (length 2.54) (name "VA2" (effects (font (size 1.27 1.27)))) (number "2" (effects (font (size 1.27 1.27)))))
   (pin passive line (at 7.62 -2.54 180) (length 2.54) (name "VB1" (effects (font (size 1.27 1.27)))) (number "3" (effects (font (size 1.27 1.27)))))
   (pin passive line (at 7.62 2.54 180) (length 2.54) (name "VB2" (effects (font (size 1.27 1.27)))) (number "4" (effects (font (size 1.27 1.27))))))))
'''
_lib_cache["ct6"] = {s[1]: s for s in find(parse(CUSTOM_SYMBOLS_TEXT), "symbol")}


def flat_symbol(lib, name):
    syms = lib_symbols(lib)
    sym = copy.deepcopy(syms[name])
    ext = first(sym, "extends")
    if ext:
        base = flat_symbol(lib, ext[1])
        base_name = ext[1]
        # override properties from derived symbol
        props = {p[1]: p for p in find(sym, "property")}
        out = [c for c in base if not (isinstance(c, list) and c and c[0] == "property" and c[1] in props)]
        # insert derived properties after head items
        idx = next(i for i, c in enumerate(out) if isinstance(c, list) and c[0] == "property") if any(
            isinstance(c, list) and c and c[0] == "property" for c in out) else 2
        out[idx:idx] = list(props.values())
        for c in out:
            if isinstance(c, list) and c and c[0] == "symbol" and c[1].startswith(base_name + "_"):
                c[1] = Q(name + c[1][len(base_name):])
        out[1] = Q(name)
        sym = out
    return sym


def embedded_symbol(lib_id):
    lib, name = lib_id.split(":")
    sym = flat_symbol(lib, name)
    sym[1] = Q(lib_id)
    return sym


def symbol_pins(lib_id):
    """-> {unit: [(number, x, y, angle, type)]} ; unit 0 = common to all units."""
    lib, name = lib_id.split(":")
    sym = flat_symbol(lib, name)
    units = {}
    for sub in find(sym, "symbol"):
        m = re.match(r".*_(\d+)_(\d+)$", sub[1])
        u, style = int(m.group(1)), int(m.group(2))
        if style > 1:
            continue
        for p in find(sub, "pin"):
            at = first(p, "at")
            num = first(p, "number")[1]
            units.setdefault(u, []).append((str(num), float(at[1]), float(at[2]), float(at[3]) if len(at) > 3 else 0.0, p[1]))
    return units


# ============================================================================
# The netlist  (single source of truth for schematic AND pcb)
# ============================================================================
FP_R = "Resistor_SMD:R_0805_2012Metric"
FP_R_HV = "Resistor_SMD:R_1206_3216Metric"
FP_C = "Capacitor_SMD:C_0805_2012Metric"
FP_C_BIG = "Capacitor_SMD:C_1206_3216Metric"

parts = []   # dicts: ref, lib_id, value, fp, pins{num: net}, sch(x,y), pcb(x,y,rot), note


def part(ref, lib_id, value, fp, pins, sch, pcb=None, rot=0, mpn="", note=""):
    parts.append(dict(ref=ref, lib_id=lib_id, value=value, fp=fp, pins=pins, sch=sch,
                      pcb=pcb, rot=rot, mpn=mpn, note=note))


# ---------------------------------------------------------------- power (5 V in)
part("J1", "Connector_Generic:Conn_01x02", "5V IN",
     "TerminalBlock_Phoenix:TerminalBlock_Phoenix_MKDS-1,5-2-5.08_1x02_P5.08mm_Horizontal",
     {"1": "VIN_RAW", "2": "GND"}, (30, 50), (6, 62, 90), mpn="KF128-5.08-2P")
part("J2", "Connector:USB_C_Receptacle_PowerOnly_6P", "USB-C 5V (power only)",
     "Connector_USB:USB_C_Receptacle_GCT_USB4125-xx-x_6P_TopMnt_Horizontal",
     {"A9": "VIN_RAW", "B9": "VIN_RAW", "A12": "GND", "B12": "GND", "A5": "CC1", "B5": "CC2", "SH": "GND"},
     (30, 90), (5, 45, 90), mpn="TYPE-C-6P")
part("R1", "Device:R", "5.1k", FP_R, {"1": "CC1", "2": "GND"}, (60, 85), (14, 40, 0))
part("R2", "Device:R", "5.1k", FP_R, {"1": "CC2", "2": "GND"}, (68, 85), (14, 50, 0))
part("F1", "Device:Polyfuse", "500mA hold", "Fuse:Fuse_1206_3216Metric",
     {"1": "VIN_RAW", "2": "VIN_F"}, (85, 50), (16, 58, 90), mpn="SMD1206P050TF")
part("D1", "Device:D_Schottky", "SS34", "Diode_SMD:D_SMA", {"2": "VIN_F", "1": "+5V"},
     (105, 50), (22, 58, 90), mpn="SS34")
part("C1", "Device:C", "22uF 16V", FP_C_BIG, {"1": "+5V", "2": "GND"}, (125, 55), (27, 58, 90))
part("FB1", "Device:FerriteBead_Small", "600R@100MHz", "Inductor_SMD:L_0805_2012Metric",
     {"1": "+3V3", "2": "+3V3A"}, (85, 110), (74, 30, 0), mpn="BLM21PG601")
part("C2", "Device:C", "10uF", FP_C, {"1": "+3V3A", "2": "GND"}, (105, 115), (74, 34, 0))
part("C3", "Device:C", "100nF", FP_C, {"1": "+3V3A", "2": "GND"}, (115, 115), (78, 34, 0))

# ---------------------------------------------------------------- bias (≈1.50 V, buffered)
part("R3", "Device:R", "12k 1%", FP_R, {"1": "+3V3A", "2": "VB_DIV"}, (160, 45), (58, 30, 90))
part("R4", "Device:R", "10k 1%", FP_R, {"1": "VB_DIV", "2": "GND"}, (160, 65), (58, 34, 90))
part("C4", "Device:C", "100nF", FP_C, {"1": "VB_DIV", "2": "GND"}, (170, 65), (58, 38, 90))
part("U1", "Amplifier_Operational:MCP6002-xSN", "MCP6002-E/SN", "Package_SO:SOIC-8_3.9x4.9mm_P1.27mm",
     {"3": "VB_DIV", "2": "VB_OUT", "1": "VB_OUT",          # A = bias buffer (unity gain)
      "5": "VB", "6": "ZS_A", "7": "V_OUT",                 # B = ZMPT transimpedance amp
      "8": "+3V3A", "4": "GND"},
     (180, 100), (66, 38, 0), mpn="MCP6002T-E/SN")
part("C5", "Device:C", "100nF", FP_C, {"1": "+3V3A", "2": "GND"}, (270, 100), (66, 32, 0))
part("R5", "Device:R", "47R", FP_R, {"1": "VB_OUT", "2": "VB"}, (225, 45), (72, 41, 0),
     note="isolates op-amp output from the 10uF bias capacitor")
part("C6", "Device:C", "10uF", FP_C, {"1": "VB", "2": "GND"}, (245, 55), (76, 41, 90))
part("C7", "Device:C", "100nF", FP_C, {"1": "VB", "2": "GND"}, (255, 55), (79, 41, 90))
part("R6", "Device:R", "1k", FP_R, {"1": "VB", "2": "VB_MON"}, (270, 45), (82, 41, 0))

# ---------------------------------------------------------------- 6 × CT channels
CT_GPIO = {1: "GPIO1", 2: "GPIO4", 3: "GPIO5", 4: "GPIO6", 5: "GPIO7", 6: "GPIO8"}
JACK_PITCH = 16.0
for n in range(1, 7):
    sx = 25 + (n - 1) * 62          # schematic block origin
    sy = 175
    px = 12 + (n - 1) * JACK_PITCH  # pcb column centre
    sig, ma, adc = f"CT{n}_SIG", f"CT{n}_MA", f"CT{n}_ADC"
    part(f"J1{n}", "Connector_Audio:AudioJack3", f"CT{n}",
         "Connector_Audio:Jack_3.5mm_CUI_SJ1-3523N_Horizontal",
         {"S": "VB", "T": sig, "R": None}, (sx, sy), (px, 82, 0), mpn="SJ1-3523N / PJ-3523")
    part(f"R1{n}1", "Device:R", "22R 0.1%", FP_R, {"1": sig, "2": ma}, (sx + 18, sy - 8), (px - 4, 68, 90),
         mpn="0805 22R 0.1% 25ppm", note="CT burden (mA-type CT only)")
    part(f"JP1{n}", "Connector_Generic:Conn_01x03", "mA|V", "Connector_PinHeader_2.54mm:PinHeader_1x03_P2.54mm_Vertical",
         {"1": "VB", "2": ma, "3": None}, (sx + 18, sy + 12), (px - 4, 61, 0),
         note="shunt 1-2 = mA CT (burden in, DEFAULT) ; 2-3 = 1V CT (burden out)")
    part(f"R1{n}2", "Device:R", "1k 1%", FP_R, {"1": sig, "2": adc}, (sx + 30, sy - 8), (px + 1, 68, 90))
    part(f"R1{n}3", "Device:R", "1k8 1%", FP_R, {"1": adc, "2": "VB"}, (sx + 38, sy + 8), (px + 4, 68, 90))
    part(f"C1{n}", "Device:C", "100nF", FP_C, {"1": adc, "2": "GND"}, (sx + 46, sy + 8), (px + 7, 68, 90))
    part(f"D1{n}", "Diode:BAT54S", "BAT54S", "Package_TO_SOT_SMD:SOT-23",
         {"1": "GND", "2": "+3V3A", "3": adc}, (sx + 30, sy + 22), (px + 3, 61, 0))

# ---------------------------------------------------------------- mains voltage sensing (ZMPT101B)
part("J5", "Connector_Generic:Conn_01x02", "230V AC (L,N)",
     "TerminalBlock_Phoenix:TerminalBlock_Phoenix_MKDS-1,5-2-5.08_1x02_P5.08mm_Horizontal",
     {"1": "AC_L", "2": "AC_N"}, (30, 245), (6, 12, 90), mpn="KF128-5.08-2P 300V")
part("F2", "Device:Fuse", "100mA T 250V", "Fuse:Fuse_Littelfuse_395Series",
     {"1": "AC_L", "2": "AC_LF"}, (60, 240), (18, 8, 0), mpn="Littelfuse 39211000440 (TR5)")
part("RV1", "Device:Varistor", "275VAC 7mm", "Varistor:RV_Disc_D7mm_W4.2mm_P5mm",
     {"1": "AC_LF", "2": "AC_N"}, (80, 255), (18, 20, 0), mpn="7D431K")
for i, (a, b) in enumerate([("AC_LF", "AC_M1"), ("AC_M1", "AC_M2"), ("AC_M2", "AC_M3"), ("AC_M3", "AC_ZP")], 1):
    part(f"R4{i}", "Device:R", "220k 1% 1206", FP_R_HV, {"1": a, "2": b}, (95 + i * 14, 240),
         (27 + (i - 1) * 4.5, 8, 90), mpn="1206 220k 1% (200V)",
         note="4 x 220k = 880k -> 0.26 mA at 230 V")
part("T1", "ct6:ZMPT101B", "ZMPT101B", "ct6:ZMPT101B",
     {"1": "AC_ZP", "2": "AC_N", "3": "VB", "4": "ZS_A"}, (175, 250), (36, 22, 0), mpn="ZMPT101B")
part("R47", "Device:R", "2k7 1%", FP_R, {"1": "ZS_A", "2": "V_OUT"}, (215, 240), (60, 44, 0),
     note="transimpedance gain: 0.26 mA x 2.7k = 0.70 V RMS at 230 V")
part("C41", "Device:C", "47nF", FP_C, {"1": "ZS_A", "2": "V_OUT"}, (215, 262), (60, 47, 0))
part("R48", "Device:R", "1k", FP_R, {"1": "V_OUT", "2": "V_ADC"}, (240, 240), (66, 47, 0))
part("C42", "Device:C", "100nF", FP_C, {"1": "V_ADC", "2": "GND"}, (255, 250), (70, 47, 90))
part("D41", "Diode:BAT54S", "BAT54S", "Package_TO_SOT_SMD:SOT-23",
     {"1": "GND", "2": "+3V3A", "3": "V_ADC"}, (285, 255), (74, 47, 0))

# ---------------------------------------------------------------- ESP32-S3-DevKitC-1 sockets
# Verify against YOUR DevKit silkscreen/pinout before ordering!
DEVKIT_LEFT = ["+3V3", "+3V3", None, "CT2_ADC", "CT3_ADC", "CT4_ADC", "CT5_ADC", None, None, "I2C_SDA",
               "I2C_SCL", "CT6_ADC", None, None, "V_ADC", "VB_MON", None, None, None, None, "+5V", "GND"]
#               3V3  3V3  RST GPIO4 GPIO5 GPIO6 GPIO7 GPIO15 GPIO16 GPIO17 GPIO18 GPIO8 GPIO3 GPIO46 GPIO9 GPIO10 11 12 13 14 5V GND
DEVKIT_RIGHT = ["GND", None, None, "CT1_ADC", None, None, None, None, None, None, None, None, None, None,
                None, None, None, None, None, None, "GND", "GND"]
#               GND TX RX GPIO1 GPIO2 42 41 40 39 38 37 36 35 0 45 48 47 21 20 19 GND GND
part("J3", "Connector_Generic:Conn_01x22", "DevKit J1 (3V3..GND)", "Connector_PinSocket_2.54mm:PinSocket_1x22_P2.54mm_Vertical",
     {str(i + 1): n for i, n in enumerate(DEVKIT_LEFT)}, (330, 60), (88, 30, 270))
part("J4", "Connector_Generic:Conn_01x22", "DevKit J3 (GND..GND)", "Connector_PinSocket_2.54mm:PinSocket_1x22_P2.54mm_Vertical",
     {str(i + 1): n for i, n in enumerate(DEVKIT_RIGHT)}, (380, 60), (88, 30 + DEVKIT_ROW_SPACING, 270))

# ---------------------------------------------------------------- OLED / I2C header
part("J6", "Connector_Generic:Conn_01x04", "I2C OLED", "Connector_PinHeader_2.54mm:PinHeader_1x04_P2.54mm_Vertical",
     {"1": "GND", "2": "+3V3", "3": "I2C_SCL", "4": "I2C_SDA"}, (300, 130), (112, 64, 0))

# ---------------------------------------------------------------- mounting holes
for i, (x, y) in enumerate([(3.5, 3.5), (116.5, 3.5), (3.5, 86.5), (116.5, 86.5)], 1):
    part(f"H{i}", "Mechanical:MountingHole", "M3", "MountingHole:MountingHole_3.2mm_M3", {},
         (450 + i * 15, 60), (x, y, 0))

# ---------------------------------------------------------------- PCB floor plan (x right, y down, mm from top-left)
# Mains block x<35.5 / y<33 is fenced by an L-shaped slot; the slot runs under the ZMPT101B between
# its primary (x=30.5) and secondary (x=40.5) pins. DevKit on the right, antenna at the top edge.
JACK_PITCH = 14.0
JACK_Y = 90.0 - 4.5            # SJ1-3523N "PCB edge" line is 4.5 mm in front of its origin
PLACE = {
    # mains
    "J5": (6, 16, 90), "F2": (9, 29, 0), "RV1": (14, 19, 0),
    "R41": (23, 25, 90), "R42": (23, 20, 90), "R43": (23, 15, 90), "R44": (23, 10, 90),
    "T1": (35.5, 16, 0),
    # ZMPT transimpedance amp + bias (LV, right of the slot)
    "R47": (47, 12, 90), "C41": (50, 12, 90), "U1": (56, 20, 0), "C5": (56, 15, 0),
    "R48": (62, 20, 90), "C42": (65, 20, 90), "D41": (68.5, 20, 0),
    "R3": (48, 20, 90), "R4": (48, 25, 90), "C4": (51, 25, 90),
    "R5": (62, 26, 0), "C6": (56, 27, 0), "C7": (56, 30, 0), "R6": (62, 30, 0),
    "FB1": (70, 26, 0), "C2": (70, 29, 0), "C3": (70, 32, 0),
    # 5 V input
    "J2": (3.5, 44, 270), "R1": (11, 41, 90), "R2": (11, 46, 90),
    "J1": (6, 58, 90), "F1": (17, 52, 90), "D1": (22, 52, 90), "C1": (27, 52, 90),
    # DevKit sockets (pin 1 = top / antenna end)
    "J3": (84, 5, 0), "J4": (84 + DEVKIT_ROW_SPACING, 5, 0),
    "J6": (114, 66, 0),
    "H1": (3.5, 3.5, 0), "H2": (116.5, 3.5, 0), "H3": (116.5, 86.5, 0), "H4": (95, 86.5, 0),
}
for n in range(1, 7):
    cx = 8 + (n - 1) * JACK_PITCH
    PLACE.update({f"J1{n}": (cx, JACK_Y, 0), f"JP1{n}": (cx - 4.5, 63, 0), f"R1{n}1": (cx - 1, 64, 90),
                  f"R1{n}2": (cx + 1.5, 64, 90), f"R1{n}3": (cx + 4, 64, 90), f"C1{n}": (cx + 1.5, 70, 90),
                  f"D1{n}": (cx + 4.5, 71, 0)})
for p in parts:
    p["pcb"] = PLACE[p["ref"]]

# PWR_FLAGs (schematic only)
PWR_FLAG_NETS = ["GND", "+3V3", "+3V3A", "+5V", "VIN_RAW", "AC_L", "AC_N"]

BOARD_W, BOARD_H = 120.0, 90.0
# GND pour outline: whole board minus the mains block and the DevKit antenna area
GND_POUR = [(38.0, 0.5), (80.0, 0.5), (80.0, 16.0), (112.0, 16.0), (112.0, 0.5),
            (BOARD_W - 0.5, 0.5), (BOARD_W - 0.5, BOARD_H - 0.5), (0.5, BOARD_H - 0.5),
            (0.5, 36.0), (38.0, 36.0)]


# ============================================================================
# Schematic writer
# ============================================================================
def snap(v, g=1.27):
    return round(round(v / g) * g, 4)
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

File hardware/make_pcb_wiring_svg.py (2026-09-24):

"""
Generate renders/pcb_full_connection.svg: the complete CT6 PCB circuit drawn as a wired diagram
(every R, C, diode, jumper, op-amp pin and GPIO), with the same designators and values as the
KiCad netlist in generate_kicad.py.

    python hardware/make_pcb_wiring_svg.py
"""
import os
import sys
from xml.sax.saxutils import escape

HERE = os.path.dirname(os.path.abspath(__file__))
sys.path.insert(0, HERE)
import generate_kicad as g  # noqa: E402

OUT = os.path.join(HERE, "renders", "pcb_full_connection.svg")
V = {p["ref"]: p["value"] for p in g.parts}          # values straight from the netlist

W, H = 1900, 1640
RED, BLK, BLU, GRN, ORG, PUR = "#d62828", "#222222", "#1d6fd6", "#2a9d3f", "#e07b00", "#7b2cbf"
MAINS_L, MAINS_N, TXT, SUB, WARN = "#8b4513", "#1f3a93", "#1b2733", "#4a5a6a", "#b01e1e"
Y3A, YVB = 470, 520                                  # +3V3A and VB buses across the CT area

s = []
add = s.append


def text(x, y, t, size=12, c=TXT, w="400", anchor="start", italic=False):
    add(f'<text x="{x}" y="{y}" font-size="{size}" fill="{c}" font-weight="{w}" text-anchor="{anchor}"'
        + (' font-style="italic"' if italic else "") + f'>{escape(str(t))}</text>')


def line(x1, y1, x2, y2, c=TXT, w=3):
    add(f'<line x1="{x1}" y1="{y1}" x2="{x2}" y2="{y2}" stroke="{c}" stroke-width="{w}" stroke-linecap="round"/>')


def poly(pts, c=TXT, w=3):
    add(f'<polyline points="{" ".join(f"{x},{y}" for x, y in pts)}" stroke="{c}" stroke-width="{w}" '
        f'fill="none" stroke-linejoin="round" stroke-linecap="round"/>')


def dot(x, y, c=TXT, r=5):
    add(f'<circle cx="{x}" cy="{y}" r="{r}" fill="{c}"/>')


def rect(x, y, w, h, fill, stroke, sw=2, rx=4, dash=None):
    add(f'<rect x="{x}" y="{y}" width="{w}" height="{h}" rx="{rx}" fill="{fill}" stroke="{stroke}" stroke-width="{sw}"'
        + (f' stroke-dasharray="{dash}"' if dash else "") + "/>")


def gnd(x, y, c=BLK):
    line(x, y, x, y + 10, c)
    line(x - 11, y + 10, x + 11, y + 10, c, 3)
    line(x - 7, y + 15, x + 7, y + 15, c, 2.5)
    line(x - 3, y + 20, x + 3, y + 20, c, 2)


def res_v(x, y1, y2, fill="#f3e2b3", stroke="#6b5518", dash=None):
    rect(x - 7, y1, 14, y2 - y1, fill, stroke, 2, 3, dash)


def res_h(x1, x2, y, fill="#f3e2b3", stroke="#6b5518"):
    rect(x1, y - 7, x2 - x1, 14, fill, stroke, 2, 3)


def cap_v(x, y, c=TXT):          # vertical wire, plates at y and y+9
    line(x - 13, y, x + 13, y, c, 3.5)
    line(x - 13, y + 9, x + 13, y + 9, c, 3.5)


def cap_h(x, y, c=TXT):          # horizontal wire, plates at x and x+9
    line(x, y - 13, x, y + 13, c, 3.5)
    line(x + 9, y - 13, x + 9, y + 13, c, 3.5)


def diode_up(x, ytop, ybot, c=TXT):   # anode at bottom, cathode (bar) at top
    add(f'<polygon points="{x - 8},{ybot} {x + 8},{ybot} {x},{ytop}" fill="{c}"/>')
    line(x - 9, ytop, x + 9, ytop, c, 3)


def diode_right(x1, x2, y, c=TXT):    # anode left, cathode right
    add(f'<polygon points="{x1},{y - 8} {x1},{y + 8} {x2},{y}" fill="{c}"/>')
    line(x2, y - 9, x2, y + 9, c, 3)


def pill(x, y, t, c, w=None, anchor="start"):
    w = w or (len(t) * 7.4 + 18)
    x0 = x - w if anchor == "end" else x
    rect(x0, y - 11, w, 22, c, c, 1, 11)
    text(x0 + w / 2, y + 4.5, t, 11.5, "#ffffff", "700", "middle")
    return x0, x0 + w


def opamp(x, y, label, pins):
    """Triangle with − input at (x, y-20), + input at (x, y+20), output at (x+80, y)."""
    add(f'<polygon points="{x},{y - 40} {x},{y + 40} {x + 80},{y}" fill="#eef3fa" stroke="{TXT}" stroke-width="2.5"/>')
    text(x + 8, y - 15, "−", 18, TXT, "700")
    text(x + 8, y + 27, "+", 18, TXT, "700")
    text(x + 26, y + 5, label, 11, SUB, "700")
    text(x - 4, y - 25, pins[0], 10.5, SUB, anchor="end")
    text(x - 4, y + 36, pins[1], 10.5, SUB, anchor="end")
    text(x + 84, y + 20, pins[2], 10.5, SUB)


def section_title(x, y, t, c=TXT):
    text(x, y, t, 17, c, "700")


# ============================================================ header
add("__HEADER__")
text(30, 40, "CT6 Energy Monitor PCB v0.1: full circuit connection diagram", 27, TXT, "700")
text(30, 66, "Every resistor, capacitor, diode, jumper and GPIO, with the same designators and values as the KiCad "
             "netlist / Gerbers in hardware/fab. ⏚ = GND. Wires that cross without a dot are NOT connected.", 14, SUB)

# ============================================================ 1. POWER INPUT
section_title(30, 100, "1 · Power input")
rect(40, 125, 76, 115, "#e9eef5", "#5b6b7b", 2, 8)
text(78, 145, "J2", 13, TXT, "700", "middle"); text(78, 160, "USB-C", 11, SUB, anchor="middle")
text(78, 173, "power only", 10, SUB, anchor="middle")
for y, t in [(185, "VBUS"), (205, "CC1"), (222, "CC2"), (236, "GND")]:
    text(112, y + 4, t, 10, SUB, anchor="end")
# VBUS -> VIN_RAW
poly([(116, 185), (200, 185)], RED); dot(116, 185, RED, 4)
# CC1 -> R1 5.1k -> GND (x=175) ; CC2 -> R2 5.1k -> GND (x=150); no crossings
poly([(116, 205), (175, 205), (175, 250)], "#4a5a6a"); res_v(175, 250, 290); gnd(175, 290)
text(185, 272, f"R1 {V['R1']}", 11, TXT, "600")
poly([(116, 222), (150, 222), (150, 250)], "#4a5a6a"); res_v(150, 250, 290); gnd(150, 290)
text(140, 272, f"R2 {V['R2']}", 11, TXT, "600", "end")
poly([(116, 236), (130, 236), (130, 320)], BLK); gnd(130, 320)
rect(40, 330, 76, 70, "#e9eef5", "#5b6b7b", 2, 8)
text(78, 352, "J1", 13, TXT, "700", "middle"); text(78, 367, "5V screw", 11, SUB, anchor="middle")
text(112, 383, "+5V", 10, SUB, anchor="end"); text(112, 397, "GND", 10, SUB, anchor="end")
poly([(116, 380), (200, 380), (200, 185)], RED); dot(200, 185, RED)
poly([(116, 394), (170, 394), (170, 410)], BLK); gnd(170, 410)
text(122, 176, "VIN_RAW", 10.5, RED, "700")
# F1, D1
line(200, 185, 240, 185, RED); rect(240, 176, 50, 18, "#ffe8a3", "#8a6d00", 2, 3); line(240, 185, 290, 185, "#8a6d00", 1.5)
text(265, 170, f"F1 {V['F1']}", 11, TXT, "600", "middle"); text(265, 208, "PTC", 10, SUB, anchor="middle")
line(290, 185, 325, 185, RED); diode_right(325, 350, 185)
text(338, 170, f"D1 {V['D1']}", 11, TXT, "600", "middle")
line(350, 185, 420, 185, RED); dot(400, 185, RED)
text(372, 208, "+5V", 11, RED, "700")
line(400, 185, 400, 230, RED); cap_v(400, 230); gnd(400, 239)
text(418, 240, f"C1 {V['C1']}", 11, TXT, "600")
pill(420, 185, "→ DevKit 5V (J3-21)", RED)
# DevKit 3V3 -> FB1 -> +3V3A
pill(250, 300, "DevKit 3V3 (J3-1,2) →", RED)
line(410, 300, 440, 300, RED); rect(440, 292, 44, 16, "#555", "#222", 1.5, 3)
text(462, 285, f"FB1 {V['FB1']}", 11, TXT, "600", "middle")
line(484, 300, 560, 300, RED); dot(510, 300, RED); dot(545, 300, RED)
text(583, 330, "+3V3A", 11, RED, "700")
line(510, 300, 510, 340, RED); cap_v(510, 340); gnd(510, 349); text(480, 385, f"C2 {V['C2']}", 10.5, TXT, "600")
line(545, 300, 545, 340, RED); cap_v(545, 340); gnd(545, 349); text(538, 400, f"C3 {V['C3']}", 10.5, TXT, "600")
poly([(560, 300), (575, 300), (575, Y3A)], RED); dot(575, Y3A, RED)
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

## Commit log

2026-09-24 ESP32-S3 AC energy monitor: CT test firmware, custom 6-CT PCB, wiring guides
    - ESPHome single-channel SCT-013 test firmware (true RMS, bias removal,
    eFuse ADC calibration, HA-editable CT ratio/burden/calibration)
    - KiCad 10 project for ESP32-S3 DevKit + 6 CT (mA/V jumper per channel)
    + on-board ZMPT101B, fully routed (ERC 0, DRC 0, parity 0), generated
    from one netlist by generate_kicad.py and routed by route_pcb.py
    - Gerbers, BOM and CPL for JLCPCB; EasyEDA connection guide SVG
    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
    [bom.csv, ct6-bom.csv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]
2026-09-24 Add full PCB circuit connection diagram (SVG)
    hardware/renders/pcb_full_connection.svg shows every resistor, capacitor,
    diode, jumper, op-amp pin and DevKit GPIO of the CT6 PCB as a wired
    diagram, generated by hardware/make_pcb_wiring_svg.py from the same
    netlist as the KiCad project.
2026-09-24 README: full project overview, files, EasyEDA/KiCad, circuit and test results
    Adds project status, breadboard test results, repository map, KiCad /
    EasyEDA / JLCPCB file guide, diagram index, GPIO map, CT channel circuit,
    jumper and Home Assistant settings, diode (D1/D11-D16/D41) explanation,
    resistor colour codes, other-PC setup, before-ordering checklist and next
    steps. The stage-1 single-CT guide is kept below as its own section.
2026-10-17 Add v0.2 EasyEDA guide: WROOM-1U module on board + ZMPT101B module backup
    ESP32-S3-WROOM-1U-N16R8 replaces the DevKit sockets, with AMS1117-3.3, USB-C
    data + USBLC6-2SC6 ESD (D+ IO20, D- IO19), EN/RESET and BOOT buttons and a
    UART header. J8 accepts a plug-in ZMPT101B module (10k/22k divider) and JP2
    selects the GPIO9 source. CT channels, bias and the on-board voltage stage are
    unchanged from v0.1. 97 parts, 51 nets, no single-pin nets.
2026-10-17 Add v0.2 KiCad schematic (WROOM-1U module + ZMPT101B module backup)
    - netlist_v02.py: single source of truth for the v0.2 KiCad schematic and the
    EasyEDA guide (module pinout checked against KiCad's ESP32-S3-WROOM-1 symbol)
    - generate_kicad_v02.py: writes hardware/kicad_v02/ (schematic only)
    - ERC: 0 electrical errors; all 242 pin connections / 51 nets match netlist_v02
    - Schematic PDF, BOM and zipped project for EasyEDA Pro import
    - SW1/SW2 use the 2-pin push-button symbol; generate_kicad.py finds a per-user
    KiCad install
